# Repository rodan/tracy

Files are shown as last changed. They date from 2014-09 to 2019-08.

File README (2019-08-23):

 gps tracker based on a MSP430F5510 uC with a gprs connection for reporting and command input.

 source:       https://github.com/rodan/tracy 
 author:       Petre Rodan <2b4eda@subdimension.ro>
 license:      GNU GPLv3

Features:
 - both hardware and software are opensource
 - an f-ram chip for input data buffering
 - resilient software architecture
 - all gps/gsm operations controlled by timer interrupts which allows control of both sub-systems in the same time
 - great flexibility given by configuration variables

 prototype pictures available here:  https://photos.app.goo.gl/5ZgdGM5Km6QHHfX5A
 documentation available here:       https://github.com/rodan/tracy/blob/master/doc/tracy_manual.pdf

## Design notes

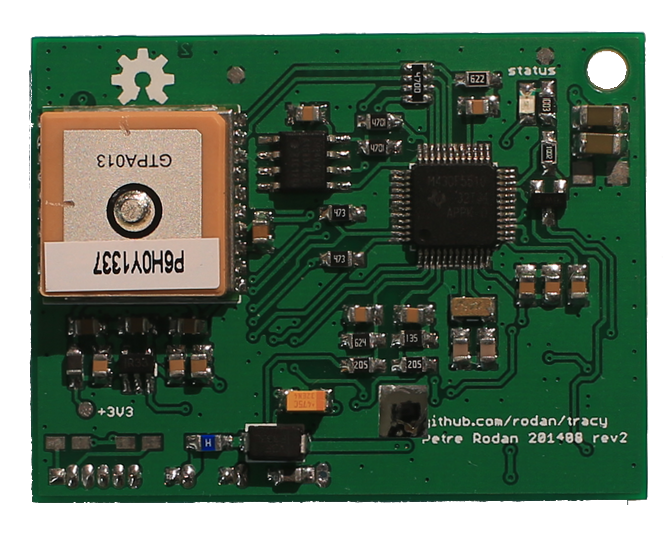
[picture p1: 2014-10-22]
doc/img/front.png

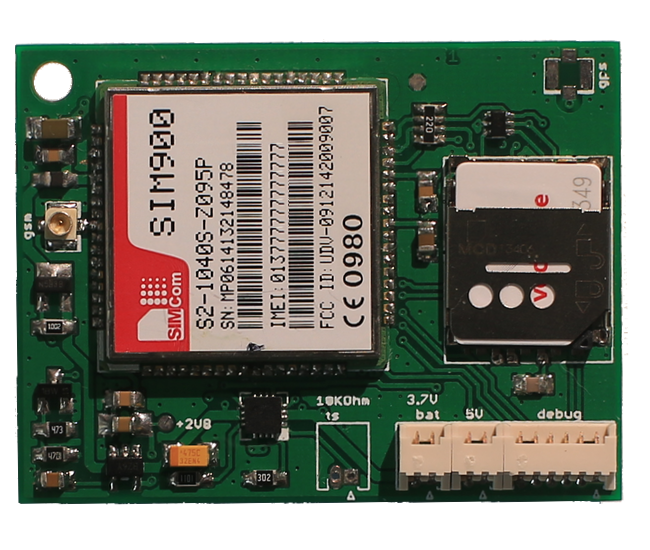
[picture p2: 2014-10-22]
doc/img/back.png

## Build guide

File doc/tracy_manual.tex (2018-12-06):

\documentclass[a4paper,twoside]{refart}

\hfuzz=10pt

\usepackage{etex}
\usepackage{longtable}
\usepackage{graphicx} 
\usepackage[bitheight=6ex]{bytefield}
\usepackage{gensymb}
\usepackage[stable]{footmisc}
\usepackage{multirow}
\usepackage[toc]{glossaries}

\makeglossaries

\usepackage{hyperref}
\hypersetup{
    colorlinks,
    citecolor=black,
    filecolor=black,
    linkcolor=black,
    urlcolor=blue
}

\usepackage{listings} % Required for inserting code snippets
\usepackage[usenames,dvipsnames]{color} % Required for specifying custom colors and referring to colors by name

\usepackage{pgfgantt}
\usepackage{tikz-timing}

\definecolor{highlight}{RGB}{255,251,204} % Code highlight color

\lstdefinelanguage{sms}
{morekeywords={code,gprs?,setup?,fix?,apn,user,pass,srv,port,vref,err.*,spl,spw,spi,spg,sml,smst,smmt,ping,set,default},
sensitive=false,
morestring=[b]",
}

\lstset{
language=sms, % Detects keywords, comments, strings, functions, etc for the language specified
backgroundcolor=\color{highlight}, % Set the background color for the snippet - useful for highlighting
basicstyle=\footnotesize\ttfamily, % The default font size and style of the code
%basicstyle=\ttfamily, % The default font size and style of the code
breakatwhitespace=false, % If true, only allows line breaks at white space
breaklines=true, % Automatic line breaking (prevents code from protruding outside the box)
captionpos=b, % Sets the caption position: b for bottom; t for top
deletekeywords={}, % If you want to delete any keywords from the current language separate them by commas
%escapeinside={\%}, % This allows you to escape to LaTeX using the character in the bracket
firstnumber=1, % Line numbers begin at line 1
frame=single, % Frame around the code box, value can be: none, leftline, topline, bottomline, lines, single, shadowbox
frameround=tttt, % Rounds the corners of the frame for the top left, top right, bottom left and bottom right positions
keywordstyle=\color{Blue}\bf, % Functions are bold and blue
morekeywords={}, % Add any functions no included by default here separated by commas
numbers=left, % Location of line numbers, can take the values of: none, left, right
numbersep=10pt, % Distance of line numbers from the code box
numberstyle=\tiny\color{Gray}, % Style used for line numbers
rulecolor=\color{black}, % Frame border color
showstringspaces=false, % Don't put marks in string spaces
showtabs=false, % Display tabs in the code as lines
stepnumber=5, % The step distance between line numbers, i.e. how often will lines be numbered
stringstyle=\color{Purple}, % Strings are purple
tabsize=2, % Number of spaces per tab in the code
}

\renewcommand*{\familydefault}{\sfdefault}
%\renewcommand*{\familydefault}{\rmdefault}
%\renewcommand*{\familydefault}{\ttdefault}
%\renewcommand*{\familydefault}{\rmdefault{ppl}}

\newglossaryentry{adc}{%
  name={ADC},
  description={analog to digital converter}
}

\newglossaryentry{cell-id}{%
  name={cell ID},
  description={cell identification code - part of the cell tower id broadcast}
}

\newglossaryentry{cell-lac}{%
  name={cell LAC},
  description={location area code - part of the cell tower id broadcast}
}

\newglossaryentry{cell-mcc}{%
  name={cell MCC},
  description={mobile country code - part of the cell tower id broadcast}
}

\newglossaryentry{cell-mnc}{%
  name={cell MNC},
  description={mobile network code - part of the cell tower id broadcast}
}

\newglossaryentry{cell-rxl}{%
  name={cell RXL},
  description={receive signal strength level - part of the cell tower id broadcast}
}

\newglossaryentry{m2m}{%
  name={M2M},
  description={machine to machine data plan - mobile subscription that covers SMS and data but no voice}
}

\newglossaryentry{pdop}{%
  name={PDOP},
  description={(3D) position dilution of precision - a value that describes the measurement's precision based on satellite geometry scattering as viewed from the ground. the lower the number the better. if it's more than 5 the calculated geographical position is not to be taken into account}
}

\newglossaryentry{f-ram}{%
  name={F-RAM},
  description={Ferroelectric RAM, is a type of non-volatile random-access memory that has far greater write-erase cycle performance than eeprom/flash/SD cards and lower power usage than DRAM, but it has storage capacity limitations that makes it more costly}
}

\newenvironment{fulltable}[1][htbp]
 {\begin{table}[#1]%
  \hspace*{-\leftmarginwidth}%
  \begin{minipage}{\fullwidth}}
 {\end{minipage}\end{table}}

\newcommand*\numcircledtikz[1]{\tikz[baseline=(char.base)]{
            \node[shape=circle,draw,fill=orange,inner sep=2pt] (char) {#1};}}

%\newglossaryentry{}{%
%  name={},
%  description={}
%}

\begin{document}
\title{Gps tracking module with gprs connectivity}
\author{Petre Rodan \url{http://www.subdimension.ro}}
\date{created September 2014, revised \today}
\maketitle

\begin{fulltable}
\begin{tabular}{ c p{8cm} }

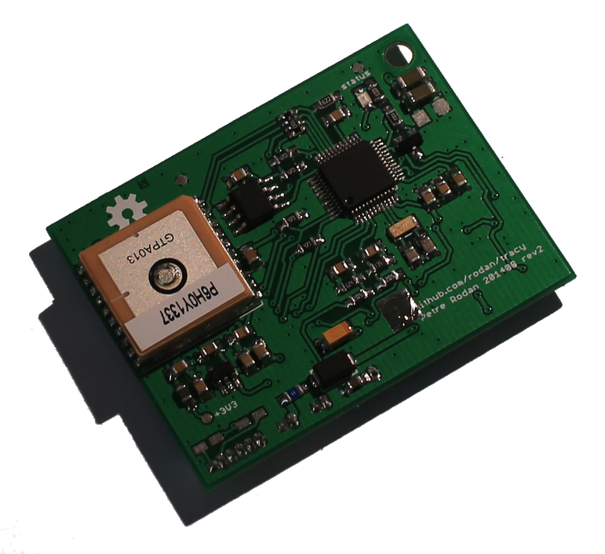
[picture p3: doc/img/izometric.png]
    \raisebox{-\totalheight}{} &
    \textbf{Description:} This module can be used to track goods wherever gsm signal is present. It is optimized for very low power consumption and has configurable timings which would make it fit to any use case scenario.

    \textbf{Main features:} both hardware and software are open-source, an f-ram chip for input data buffering, resilient software architecture, all gps/gsm operations controlled by timer interrupts which allows control of both subsystems in the same time, great flexibility given by configuration variables

    \textbf{Size:} 50mm x 38mm x 9mm
     
    \textbf{Voltage input:} 3.7V battery and optional 5V DC for charging

\end{tabular}
\end{fulltable}

\tableofcontents
\newpage

\section{Principles of operation}
Geographic coordinates are obtained by decoding NMEA sentences received from the GPS chipset and then transmitted via the mobile phone network to a web server. The server stores the received information into a database and provides it on demand to the end-user.

Cell tower identifiers are also transmitted in the same packet and this allows approximate localization when the gps signal is obstructed. When the gsm signal is missing data is being stored on the device and it's transmission will resume once connection is re-established.

\section{What's included}

1 x tracking module \\
1 x GPRS antenna with ufl adapter (manufacturer id: WLS119E1B) \\
2 x 2 pin Molex picoblade connectors and short cable for battery and DC input (manufacturer id: MOLEX 0510210200 and MOLEX 0500798000) \\
1 x 6 pin Molex picoblade connector and crimp terminals for creating a programming cable (manufacturer id: MOLEX 0510210600 and MOLEX 0500798000) \\
1 x shrink tube

Soldering of the wires is needed. Batteries, sim cards and enclosures are not included.

\section{Quick reference guide}

\subsection{Getting started}

\subsubsection{Requirements}

\marginlabel{Warning} Special care must be taken with the gprs antenna. It has to be connected to the connector marked 'gprs' at all times or otherwise the module could be damaged.

This module works best with two power sources. One 3.7V Li-Polymer/Li-Ion cell (at least 2000mAh recommended) and a 5V input DC that is only used for recharging the cell. Only the second one is optional due to the fact that for very short bursts the gprs modem needs more current than the DC input can handle. This circuitry is USB power friendly. If the module gets installed onto a vehicle, a high efficiency DC-DC converter can be provided to lower the voltage from up to 24V to the 5V needed. Double check the polarity on the connectors before attempting to apply any power to the device. Pin 1 is marked on the silkscreen with a small triangle and that represents the ground (negative) terminal for both the battery and the DC inputs.

The user will also need a mobile phone in order to send commands to the module via SMS and a web browser to visualize the generated data.

\subsubsection{SIM cards and initial setup}

Below is a step-by-step guide for installing a local SIM card into the tracking module. The setup of a 'Vodafone prepay card' is shown as an example.

\begin{itemize}
    \item buy a SIM card. any SIM card will do: prepay-ed, subscription (but do keep in mind that no voice transmission will ever be used on this SIM tho), machine to machine (also known as \gls{m2m}). mini SIM form factor cards are needed.
    \item obtain the associated phone number and enter it into your phone's address-book - don't forget to also add the country prefix so you can contact the tracker while abroad.
    \item place the newly purchased SIM card into a mobile phone
    \item if it has no initial credit, fill it with at least 5EUR
    \item make sure no PIN is set on the SIM itself
    \item disable any 'best value plan' the provider might have selected - this SIM will mostly be used to connect to the internet, and it will send a minimal number of SMS messages during the setup process. the only extra options that are needed are the cheapest internet plan available ('100MB internet for 1 Month - 2EUR' for vodafone). also activate data roaming.
    \item disable 'VOX voicemail' by calling \#\#002\#
    \item place the SIMs back into their proper locations: the newly purchased one in the tracker and your old one into the phone.
    \item while inserting the SIM into the tracker write down the 15 IMEI digits that you see written on the SIM900 IC that is adjacent to the SIM holder.
    \item send a SMS from the phone to the tracker that contains:

\begin{lstlisting}
code 5551
\end{lstlisting}

'5551' will need to be replaced by the last 4 digits you wrote down during the previous step

    \item power on the tracker and wait. it only connects to the gsm network every 15 minutes by default and it has a 1 minute interval in which it's actively listening to incoming SMS messages. once the code is received and acknowledged you will get a 'code ok' reply on the phone. from this moment on you can send commands to the tracker.
\end{itemize}

\subsection{gprs setup}

In order for the module to connect to the internet to send out the tracking data it needs a working gprs connection to the mobile service provider. This connection is established only if a set of credentials (\verb"apn", \verb"username" and \verb"password") are used to authenticate the device. You can ask your mobile phone company to provide these. Sometimes one company has customized \verb"apn" and/or \verb"usernmames" for each sim card type, so don't rely on web searches.

Once you get your correct credentials, send them as 3 different SMS commands to the device:

\begin{lstlisting}
apn STRING
\end{lstlisting}
\begin{lstlisting}
user STRING
\end{lstlisting}
\begin{lstlisting}
pass STRING
\end{lstlisting}

\marginlabel{Warning} All strings can be max 20 characters long. If you need more on any of them please contact me.

You can check if all data has been received ok with the following command:

\begin{lstlisting}
gprs?
\end{lstlisting}

\subsection{Web visualization of data}

You can check all the info the tracker sends out by visiting \\ \verb"http://www.subdimension.ro/scripts/l1?i=IMEI_NUMBER" .\\
the \verb"IMEI_NUMBER" is a 15 digit number and it's written on the sim900 module.

This project offers the possibility to advanced users to redirect the tracking data to another web server.
Two commands control the location where HTTP POST packets are sent:

\begin{lstlisting}
srv your.server.com
\end{lstlisting}

\begin{lstlisting}
port port_number
\end{lstlisting}

\marginlabel{Warning} All strings can be max 20 characters long. If you need more on any of them please contact me.

The post request will be sent to \verb"http://your.server.com:port_number/u1". u1 has to be a CGI script (or an alias to one) that decodes the binary packets sent. See Section~\ref{sec:post-packets} for details.

\subsection{SMS commands}

\begin{tabular}{ |l|p{8cm}| }
    \hline
        command & 
\begin{lstlisting}
code STRING
\end{lstlisting} \\
        action & pair a phone to the tracker.
STRING has to be the last 4 digits of the SIM900's IMEI \\ \hline
\end{tabular}

\begin{tabular}{ |l|p{8cm}| }
    \hline
        command & 
\begin{lstlisting}
gprs?
\end{lstlisting} \\
        action & show APN, USER, PASSWORD that are currently used in order to authenticate for a gprs session \\ \hline
\end{tabular}

\begin{tabular}{ |l|p{8cm}| }
    \hline
    \multicolumn{2}{|l|}{} \\
    \hline
        command & 
\begin{lstlisting}
setup?
\end{lstlisting} \\
        action & show a hex value containing current switches \\ \hline
\end{tabular}

\begin{tabular}{ |l|p{8cm}| }
    \hline
        command & 
\begin{lstlisting}
fix?
\end{lstlisting} \\
        action & 
try to send back a GPS fix as a SMS reply \\ \hline
\end{tabular}

\begin{tabular}{ |l|p{8cm}| }
    \hline
        command & 
\begin{lstlisting}
ping
\end{lstlisting} \\
        action & 
a HTTP POST is sent with all available data once this command is received \\ \hline
\end{tabular}

\begin{tabular}{ |l|p{8cm}| }
    \hline
        command & 
\begin{lstlisting}
default
\end{lstlisting} \\
        action & 
restores ALL variables to the factory defaults and reboots the device. the user will have to use the \verb"code" command again to pair it's phone\\ \hline
\end{tabular}

\begin{tabular}{ |l|p{8cm}| }
    \hline
        command & 
\begin{lstlisting}
apn STRING
\end{lstlisting} \\
        default & live.vodafone.com \\
        action & 
set the gprs apn value - max 20 char long

in case STRING is missing, an empty apn is used 

should be set to 'net' for an orange SIM \\ \hline
\end{tabular}

\begin{tabular}{ |l|p{8cm}| }
    \hline
        command & 
\begin{lstlisting}
user STRING
\end{lstlisting} \\
        default & live \\
        action & 
set the gprs user  - max 20 char long

in case STRING is missing, an empty username is used  \\ \hline
\end{tabular}

\begin{tabular}{ |l|p{8cm}| }
    \hline
        command & 
\begin{lstlisting}
pass STRING
\end{lstlisting} \\
        default & vodafone \\
        action & 
set the gprs pass - max 20 char long
in case STRING is missing, an empty password is used  \\ \hline
\end{tabular}

\begin{tabular}{ |l|p{8cm}| }
    \hline
        command & 
\begin{lstlisting}
srv STRING
\end{lstlisting} \\
        default & t.subdimension.ro \\
        action & 
what server to contact in order to send the tracking data \\ \hline
\end{tabular}

\begin{tabular}{ |l|p{8cm}| }
    \hline
        command & 
\begin{lstlisting}
port STRING
\end{lstlisting} \\
        default & 80 \\
        action & 
TCP port used during connection to the server  \\ \hline
\end{tabular}

\begin{tabular}{ |l|p{8cm}| }
    \hline
        command & 
\begin{lstlisting}
vref STRING
\end{lstlisting} \\
        default & 198 \\
        action & 
STRING is a number between 190 and 210 that acts as calibration coefficient to the on board \gls{adc}. only used if the voltage values reported by the module differ from the measured ones \\ \hline
\end{tabular}

\begin{tabular}{ |l|p{8cm}| }
    \hline
        command & 
\begin{lstlisting}
err?
\end{lstlisting} \\
        action & 
shows a hex value in case there were any errors logged in the device. this value gets reset when all power is lost, when an 'err?' command is replied to or after a HTTP POST packet is sent out/stored to \gls{f-ram}. only used for debug  \\ \hline
\end{tabular}

\begin{tabular}{ |l|p{8cm}| }
    \hline
        command & 
\begin{lstlisting}
spt?
\end{lstlisting} \\
        action & 
shows a list of gps related timing values\\ \hline
\end{tabular}

\begin{tabular}{ |l|p{8cm}| }
    \hline
        command & 
\begin{lstlisting}
smt?
\end{lstlisting} \\
        action & 
shows a list of gprs related timing values\\ \hline
\end{tabular}

\begin{tabular}{ |l|p{8cm}| }
    \hline
        commands & 
\begin{lstlisting}
spl STRING
\end{lstlisting}
\begin{lstlisting}
spw STRING
\end{lstlisting}
\begin{lstlisting}
spi STRING
\end{lstlisting}
\begin{lstlisting}
spg STRING
\end{lstlisting}
\begin{lstlisting}
sml STRING
\end{lstlisting}
\begin{lstlisting}
smst STRING
\end{lstlisting}
\begin{lstlisting}
smmt STRING
\end{lstlisting} \\
        action &
timing variables. see section \ref{sub:timing} for details.
\\ \hline
\end{tabular}

\section{Developer guide}
\subsection{Software}

All the documentation, sources and hardware schematics are provided as Open Source in order to encourage further improvements by the community. The TI spy-bi-wire protocol can be used to re-flash the enclosed microcontroller.

Firmware is written in C and it's created to be fully non-blocking and interrupt driven. The server-side scripts are in perl and bash.

Any web server can be used to receive the binary data sent from the tracker. The unpack() function present in perl, python, php will reconstruct the information and make it ready to be inserted into a database. Special care has to be taken so that the web server's reply header is as short as possible. If it's too long the module will not parse it properly and the data flow will be disrupted. In case nginx is used using the following settings are highly recommended:

\begin{lstlisting}
more_clear_headers 'Server';
more_clear_headers 'Date';
more_clear_headers 'Content-Type';
more_clear_headers 'Transfer-Encoding';
more_clear_headers 'Connection';
\end{lstlisting}

Provided scripts have the following run time dependencies (some are optional):

\begin{itemize}
    \item perl at least ver 5.8.2
    \item sqlite at least ver 3.0.0
    \item bash
    \item nginx
    \item fcgi
\end{itemize}

\subsubsection{Tweaking the firmware}

The original source code is kept in a git repository at github.com.
One can grab a copy by running

\begin{lstlisting}
git clone http://github.com/rodan/tracy
\end{lstlisting} 

or by downloading a snapshot archive

\begin{lstlisting}
wget https://github.com/rodan/tracy/archive/master.zip
\end{lstlisting} 

compiling is as easy as
\begin{lstlisting}
cd firmware
make clean
make
\end{lstlisting} 

The following packages are used to compile and manage the firmware:

\begin{itemize}
    \item msp430-gcc (ver 4.6.3\_p20120406 has been used)
    \item msp430-binutils (2.22\_p20120911)
    \item msp430-libc (20120716)
    \item msp430mcu (20120716)
    \item mspdebug (0.22)
\end{itemize}

Burning the firmware can be achieved with any MSP430 programmer that supports SPY-Bi-Wire. 

\marginlabel{Warning} Specialized programmers can detect the 2.8V rail the microcontroller uses and will not send signals with a higher voltage. Anything higher than 3V is just asking for trouble. 

mspdebug can be used to program the firmware:

\begin{lstlisting}
mspdebug rf2500 "prog proj.elf"
\end{lstlisting}

\subsubsection{HTTP POST packets}
\label{sec:post-packets}

Tracking information is sent to the server by TCP packets via the HTTP POST method. A web server is thus needed to receive the data and feed it to the parsing script (see \verb"server/scripts/u1" in the repository).

In order to have a good bandwidth usage the data is sent in a binary format and the \gls{f-ram} chip that is being used allows the data to be buffered and sent out at set intervals. Most scripting languages have an unpack() function that can correctly decode these packets. A sample perl script is provided in the repository (see \verb"server/scripts/l1").

\begin{figure}[htbp]
  \centering
  \begin{bytefield}{32}
    \bitheader{0,0} \\
    \begin{rightwordgroup}{HTTP \\ POST \\ method \\ header}
        \bitbox{32}{POST /u1 HTTP/1.0} \\
        \bitbox{32}{Host: trk.subdimension.ro} \\
        \bitbox{32}{Content-Type: application/binary} \\
        \bitbox{32}{Content-Length: 00000}
    \end{rightwordgroup} \\

    \begin{rightwordgroup}{one\\ segment}
    \wordbox[lrt]{1}{
      \parbox{0.6\width}{\centering at least one subsegment}} \\
    \skippedwords \\
    \wordbox[lrb]{1}{} 
  \end{rightwordgroup}
  \end{bytefield}
  \caption{packet format}
  \label{fig:packetformat}
\end{figure}

Each positional measurement will be placed in a subsegment. At least one of these subsegments will constitute one segment that is sent out together with a HTTP header to create an HTTP POST request (see Figure~\ref{fig:packetformat}).

\begin{figure}[htbp]
  \centering
  \begin{bytefield}{32}
    \bitheader{0,7-8,15-16,23-24,31} \\
    \begin{rightwordgroup}{subsegment \\ header}
        \bitbox{16}{version} &&
        \bitbox[tlr]{16}{} \\
        \wordbox[lr]{1}{\parbox{0.6\width}{\centering 15 byte IMEI}} \\
        \skippedwords \\
        \wordbox[lrb]{1}{} \\ 
        \bitbox{16}{settings} &&
        \bitbox{16}{$V_{BAT}$} \\
        \bitbox{16}{$V_{RAW}$} &&
        \bitbox{16}{errors} \\
        \bitbox{16}{message id} &&
        \bitbox{8}{payload descriptor} &&
        \bitbox[tlr]{8}{} \\
        \bitbox[rl]{32}{timestamp} \\
        \bitbox[rlb]{8}{} &&
        \bitbox[tl]{24}{}
    \end{rightwordgroup} \\
    \begin{rightwordgroup}{payload}
    \\
    \bitbox[lrb]{32}{\dots gps and/or gprs payload}
    \end{rightwordgroup}
  \end{bytefield}
  \caption{subsegment format}
  \label{fig:subsegment-format}
\end{figure}

\begin{figure}[htbp]
  \centering
  \begin{bytefield}{32}
    \bitheader{0,7-8,15-16,23-24,31} \\
    \begin{rightwordgroup}{gps \\ data}
        \bitbox{32}{latitude (float)} \\
        \bitbox{32}{longitude (float)} \\
        \bitbox{16}{\gls{pdop}} &&
        \bitbox{16}{speed} \\
        \bitbox{16}{heading} &&
        \bitbox{16}{system time} \\
        \bitbox{16}{system time} &&
        \bitbox[btl]{16}{geofence distance} \\
        \bitbox[btr]{16}{geofence distance} &&
        \bitbox{16}{geofence bearing}
    \end{rightwordgroup}
  \end{bytefield}
  \caption{gps payload}
  \label{fig:gps_payload}
\end{figure}

\begin{figure}[htbp]
  \centering
  \begin{bytefield}{32}
    \bitheader{0,7-8,15-16,23-24,31} \\
    \begin{rightwordgroup}{gprs \\ data}
        \bitbox{16}{\gls{cell-rxl}} &&
        \bitbox{16}{\gls{cell-mcc}} \\
        \bitbox{16}{\gls{cell-mnc}} &&
        \bitbox{16}{\gls{cell-id}} \\
        \bitbox{16}{\gls{cell-lac}}
    \end{rightwordgroup}
  \end{bytefield}
  \caption{gprs payload}
  \label{fig:gprs_payload}
\end{figure}

Each subsegment (shown in Figure~\ref{fig:subsegment-format}) has a header containing the timestamp at the time of the fix, modem IMEI, system voltages, previous errors detected, basic device configuration, an auto increment id and a byte that describes the type of the positional data. This can either be a GPS fix (Figure~\ref{fig:gps_payload}) and/or one up to four tower identification strings (Figure~\ref{fig:gprs_payload}).

The tower identification strings are post-processed on the web server and a \emph{very} approximate geographic position is obtained.

These subsegments are simply concatenated together to constitute the final segment being sent. The size of one such segment varies but SIM900's internal buffering limits it up to 1000bytes. During one GPRS session one up to \verb"MAX_SEG" are sent out at a time. If GPRS connections cannot be established for a long interval and \verb"MAX_SEG" is reached then the oldest segment is freed in order to make place for new data.

\newpage
\subsubsection{Timings and intervals}
\label{sub:timing}

This tracking module allows fine-grained timing customization. It can either preserve battery life for more than a month when sparse measurements are being made or it can record positional data every 10 seconds if needed. Either behavior can be set by the user via SMS commands, without the need to change the firmware.

A 'reset to factory settings' function is also provided in case the user needs to return to known-good timing values.

Default values for the gps intervals are depicted in Table~\ref{gps_diag}. The yellow time intervals are configurable: the entire loop takes 180 seconds - from which in the first 135 the gps module is powered off, a 45 sec warmup brings the device to life and it should be enough to ensure a good fix at the end of that interval. During the invalidation period the module will choose the fix with the best \gls{pdop} value and that will get stored into \gls{f-ram}.

\begin{table}[ht]
\begin{ganttchart}[
vgrid,
bar/.append style={fill=yellow, rounded corners=3pt},
bar left shift=.15,
bar right shift=-.15,
bar top shift=.4,
bar height=.2,
group left shift=0,
group right shift=0,
group peaks tip position=0,
group peaks height=.4,
milestone/.append style={fill=orange, rounded corners=3pt}
]{0}{18}
\ganttbar{loop}{0}{18} \\
\ganttbar{warmup}{13}{18} \\
\ganttbar{invalidate}{16}{18} \\
\ganttmilestone{store fix}{18} \\
\ganttbar[bar/.append style={fill=gray}]{gps off/on}{0}{12}
\ganttbar[bar/.append style={fill=red}]{}{13}{18}
\end{ganttchart}
\caption{\em default time intervals for the gps subsystem}
\label{gps_diag}
\end{table}

If much more frequent gps data needs to be acquired, ie\\
\verb"loop interval" $\leq$ \verb"warmup interval" + \verb"30s" \\
then the gps will never be powered off. See Table~\ref{gps_diag_10s} for an example where all gps intervals are set to 10 seconds.

\begin{table}[ht]
\begin{ganttchart}[
vgrid,
bar/.append style={fill=yellow, rounded corners=3pt},
bar left shift=.15,
bar right shift=-.15,
bar top shift=.4,
bar height=.2,
group left shift=0,
group right shift=0,
group peaks tip position=0,
group peaks height=.4,
milestone/.append style={fill=orange, rounded corners=3pt}
]{0}{18}
\ganttbar{loop}{0}{18} \\
\ganttbar{warmup}{0}{18} \\
\ganttbar{invalidate}{0}{18} \\
\ganttmilestone{store fix}{18} \\
\ganttbar[bar/.append style={fill=gray}]{gps off/on}{0}{0}
\ganttbar[bar/.append style={fill=red}]{}{0}{18}
\end{ganttchart}
\caption{\em 10s loop for the gps subsystem}
\label{gps_diag_10s}
\end{table}

As a rule of thumb try to have at least 45 seconds as the warmup interval in case the gps gets powered off.
And given the fact that the gps is set to send data every two seconds to the microcontroller make sure the invalidation interval is at least 6-8 seconds.

Unlike the gps, the gsm modem needs to be kept off most of the time since it is by far the most power hungry subsystem on this module.
Also a little known fact is that internet data plans have small hidden costs that can add up in time. Sometimes there is a minimum data unit (between 1-10kbytes) that gets counted for every established gprs connection, also while in roaming each gprs initialization has a cost associated with it.
So depending on your gsm provider and use case, you want to get the best trade-off using the configurable variables described in this section.

The modem gets woken up by one of these two triggers:

\begin{itemize}
    \item a periodic check for any new SMS command to be acted upon. this wake-up has no costs associated with it if no SMS reply is to be sent back to the user \\ trigger controlled by \verb"gprs loop interval"
    \item upload of data stored in \gls{f-ram} via gprs. SMS commands are also accepted at this point. this trigger can happen either because enough data has piled up in the memory, one of the \verb"gprs tx interval"s has been reached, the \verb"ping" command was received or the module just started to move after being stationary. \\ trigger controlled by \verb"gprs static tx interval" when the module is not moving or \verb"gprs moving tx interval" otherwise.
\end{itemize}

Whatever is the reason for the modem startup, the neighboring tower cell IDs are stored as a secondary (but less precise) positioning method. 

The module behavior when using the default gprs interval settings is shown in a simplified form in Table~\ref{gsm_diag}. Every 900 seconds the \verb"gprs loop interval" wakes up the modem for a 2 minute period in which possible SMSs are parsed and tower cell IDs are captured.

A movement that was detected triggers an upload of data and makes the next upload happen after 600sec (\verb"gprs moving tx interval"). The next transfer will happen after 3600sec (\verb"gprs static tx interval") since the module is not moving.

\begin{table}[ht]
\scalebox{0.48}{
\begin{tikztimingtable}
 loop trigger & 1H 9L 1H 9L 1H 9L 1H 9L 1H 9L 1H 9L 1H 9L 1H 9L 1H 4L\\
 movement & 2L 3H 80L \\
 tx trigger & 2L 1H 6L 1H 36L 1H 36L 1H 1L \\
\extracode
    \tablerules
\end{tikztimingtable}
}
\caption{\em default module behavior}
\label{gsm_diag}
\end{table}

\subsubsection{List of timing variables}

\label{sms:spl}
\begin{tabular}{ |l|c|c|c|c| }
    \hline
    \multicolumn{1}{|c|}{\multirow{2}{*}{\textbf{gps loop interval}}} & \multicolumn{3}{|c|}{value} & \multicolumn{1}{|c|}{\multirow{2}{*}{unit}} \\ \cline{2-4}
    \multicolumn{1}{|c|}{} & min & default & max & \\ \hline
    value & 10 & 180 & 65535 & seconds \\ \hline
    sms command to set & \multicolumn{4}{|l|}{\textbf{spl} $value$} \\ \hline
    sms command to view & \multicolumn{4}{|l|}{\textbf{spt?}} \\ \hline
    description & \multicolumn{4}{|p{7cm}|}{sets the interval between two gps measurement sessions} \\ \hline
\end{tabular}

\label{sms:spw}
\begin{tabular}{ |l|c|c|c|c| }
    \hline
    \multicolumn{1}{|c|}{\multirow{2}{*}{\textbf{gps warmup interval}}} & \multicolumn{3}{|c|}{value} & \multicolumn{1}{|c|}{\multirow{2}{*}{unit}} \\ \cline{2-4}
    \multicolumn{1}{|c|}{} & min & default & max & \\ \hline
    value & 0 & 45 & 65535 & seconds \\ \hline
    sms command to set & \multicolumn{4}{|l|}{\textbf{spw} $value$} \\ \hline
    sms command to view & \multicolumn{4}{|l|}{\textbf{spt?}} \\ \hline
    description & \multicolumn{4}{|p{7cm}|}{time interval between gps powerup and the actual measurement} \\ \hline
\end{tabular}

\label{sms:spi}
\begin{tabular}{ |l|c|c|c|c| }
    \hline
    \multicolumn{1}{|c|}{\multirow{2}{*}{\textbf{gps invalidate interval}}} & \multicolumn{3}{|c|}{value} & \multicolumn{1}{|c|}{\multirow{2}{*}{unit}} \\ \cline{2-4}
    \multicolumn{1}{|c|}{} & min & default & max & \\ \hline
    value & 0 & 20 & 65535 & seconds \\ \hline
    sms command to set & \multicolumn{4}{|l|}{\textbf{spi} $value$} \\ \hline
    sms command to view & \multicolumn{4}{|l|}{\textbf{spt?}} \\ \hline
    description & \multicolumn{4}{|p{6.8cm}|}{time interval at the end of the measurement session during which the gps fix with the best \gls{pdop} is searched for} \\ \hline
\end{tabular}

\verb"spi" must be a smaller value then \verb"spl".

\label{sms:spg}
\begin{tabular}{ |l|c|c|c|c| }
    \hline
    \multicolumn{1}{|c|}{\multirow{2}{*}{\textbf{gps geofence trigger}}} & \multicolumn{3}{|c|}{value} & \multicolumn{1}{|c|}{\multirow{2}{*}{unit}} \\ \cline{2-4}
    \multicolumn{1}{|c|}{} & min & default & max & \\ \hline
    value & 0 & 300 & 65535 & meters \\ \hline
    sms command to set & \multicolumn{4}{|l|}{\textbf{spg} $value$} \\ \hline
    sms command to view & \multicolumn{4}{|l|}{\textbf{spt?}} \\ \hline
    description & \multicolumn{4}{|p{7cm}|}{minimal distance between two consecutive fixes at which the device is considered non-stationary} \\ \hline
\end{tabular}

Heavy cloud coverage or large adjacent buildings can obscure or create multipath errors in the gps signal detection. It is thus advisable to not set the \textbf{spg} variable too low in order to minimize false-positives.

\label{sms:sml}
\begin{tabular}{ |l|c|c|c|c| }
    \hline
    \multicolumn{1}{|c|}{\multirow{2}{*}{\textbf{gprs loop interval}}} & \multicolumn{3}{|c|}{value} & \multicolumn{1}{|c|}{\multirow{2}{*}{unit}} \\ \cline{2-4}
    \multicolumn{1}{|c|}{} & min & default & max & \\ \hline
    value & 180 & 900 & 65535 & seconds \\ \hline
    sms command to set & \multicolumn{4}{|l|}{\textbf{sml} $value$} \\ \hline
    sms command to view & \multicolumn{4}{|l|}{\textbf{smt?}} \\ \hline
    description & \multicolumn{4}{|p{7cm}|}{time interval between two gsm connection attempts (these are used to get tower id data and to receive and parse sms commands)} \\ \hline
\end{tabular}

each application needs a different trade-off between sms responsiveness and low power consumption.

\label{sms:smst}
\begin{tabular}{ |l|c|c|c|c| }
    \hline
    \multicolumn{1}{|c|}{\multirow{2}{*}{\textbf{gprs static tx interval}}} & \multicolumn{3}{|c|}{value} & \multicolumn{1}{|c|}{\multirow{2}{*}{unit}} \\ \cline{2-4}
    \multicolumn{1}{|c|}{} & min & default & max & \\ \hline
    value & 180 & 3600 & 65535 & seconds \\ \hline
    sms command to set & \multicolumn{4}{|l|}{\textbf{smst} $value$} \\ \hline
    sms command to view & \multicolumn{4}{|l|}{\textbf{smt?}} \\ \hline
    description & \multicolumn{4}{|p{7cm}|}{time interval between two HTTP POSTs when the device is stationary (see \textbf{spg} \ref{sms:spg})} \\ \hline
\end{tabular}

\label{sms:smmt}
\begin{tabular}{ |l|c|c|c|c| }
    \hline
    \multicolumn{1}{|c|}{\multirow{2}{*}{\textbf{gprs moving tx interval}}} & \multicolumn{3}{|c|}{value} & \multicolumn{1}{|c|}{\multirow{2}{*}{unit}} \\ \cline{2-4}
    \multicolumn{1}{|c|}{} & min & default & max & \\ \hline
    value & 180 & 600 & 65535 & seconds \\ \hline
    sms command to set & \multicolumn{4}{|l|}{\textbf{smmt} $value$} \\ \hline
    sms command to view & \multicolumn{4}{|l|}{\textbf{smt?}} \\ \hline
    description & \multicolumn{4}{|p{7cm}|}{time interval between two HTTP POSTs when the device is moving (see \textbf{spg} \ref{sms:spg})} \\ \hline
\end{tabular}

all the timings in this section are used for scheduling the respective actions. the final timestamps received in the web reports will not follow exactly the values entered. this happens because the device tries to get the best fix possible in the \textbf{spi} interval based on \gls{pdop} measurements and also because most actions performed are dependent on both outside factors (how quickly a good fix is received from the gps, mobile service availability, how many sms actions need to be executed) as well as local interactions (the gprs modem can only perform one task at any given time).

\newpage
\subsection{Hardware}

\subsubsection{Absolute maximum ratings}

\begin{tabular}{ |c|c|l|c|c|c| }
    \hline
    \multicolumn{3}{|c|}{} & \multicolumn{2}{|c|}{value} & unit \\ \cline{4-6}
    \multicolumn{3}{|c|}{} & min & max & \\ \hline
    \multicolumn{1}{|c|}{\multirow{2}{*}{$V_{I}$}} & \multicolumn{1}{|c|}{\multirow{2}{*}{input voltage}} &    IN (with respect to VSS) & -0.3    & 28  & V \\ \cline{3-6}
                &                       &  VBAT (with respect to VSS)   & -0.3  & 5   & V \\ \hline
    $V_{IO}$ & \multicolumn{2}{|l|}{IO voltage thru the debug connector}                      & -0.3  & 3.1 & V \\ \hline
    $T_{stg}$   & \multicolumn{2}{|l|}{storage temperature}             & -65   & 150 & \degree C \\  \hline
    $T_{op}$   & \multicolumn{2}{|l|}{operating temperature}          & 0     & 125 & \degree C \\  \hline
\end{tabular}

Stresses above those listed in absolute maximum ratings may cause permanent damage to the device. This is a stress rating only, functional operation of the device at these or any other conditions above those indicated in the operational section of this specification is not implied. Exposure to absolute maximum rating conditions for extended periods may affect device reliability.

\subsubsection{Electrical characteristics}

\begin{tabular}{ |c|l|c|c|c|c| }
    \hline
    \multicolumn{2}{|c|}{} & \multicolumn{3}{|c|}{value} & unit \\ \cline{3-6}
    \multicolumn{2}{|c|}{} & min & typ & max & \\ \hline
    $V_{I}$ & input voltage range                      & 4.35  & 5     & 6.4  & V \\ \hline
    $I_{I}$ & input current                            & X     & X     & 1.5  & A \\ \hline
    $V_{BAT}$ & battery voltage range                  & 3.5   &       & 4.1  & V \\ \hline
    $I_{BAT}$ & battery current on sim900 poweron      &       &       & 3200 & mA \\ \hline
    $I_{BAT}$ & battery current while sim900 tx        &       &       & 1600 & mA \\ \hline
    $I_{BAT}$ & battery current while gps on           &       & 25    & 45   & mA \\ \hline
    $I_{BAT}$ & battery current while sleeping         & 70    &       & 75   & $\mu$A \\ \hline
    $I_{CHG}$ & battery charging current \footnotemark &       & 0.3   &   & A \\ \hline
    $V_{IO}$ & IO voltage thru the debug connector     & 0     &       & 2.8  & V \\ \hline
\end{tabular}

\footnotetext{The charging current is configurable by changing the value of R11. See the module schematic and the bq24072 datasheet for details}

\subsubsection{Components}

\begin{fulltable}
\begin{tabular}{ c c }
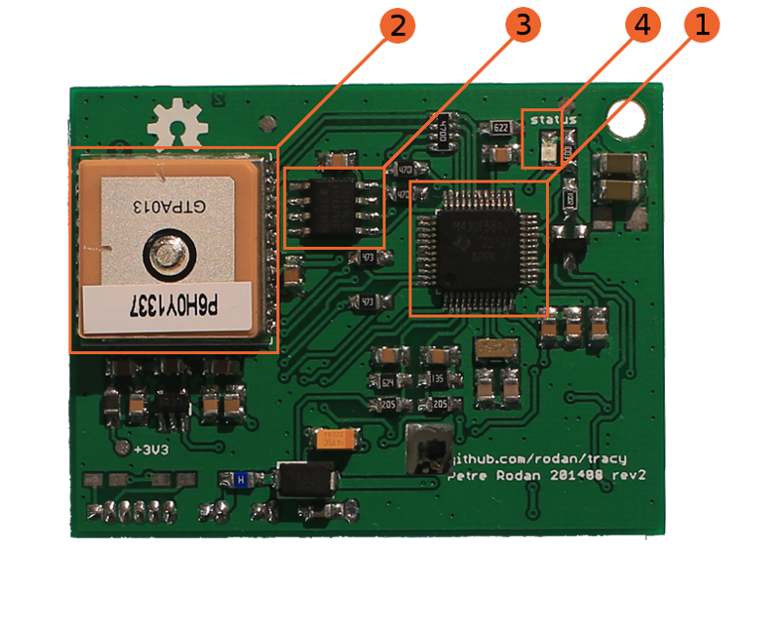
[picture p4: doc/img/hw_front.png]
    \raisebox{-\totalheight}{} &
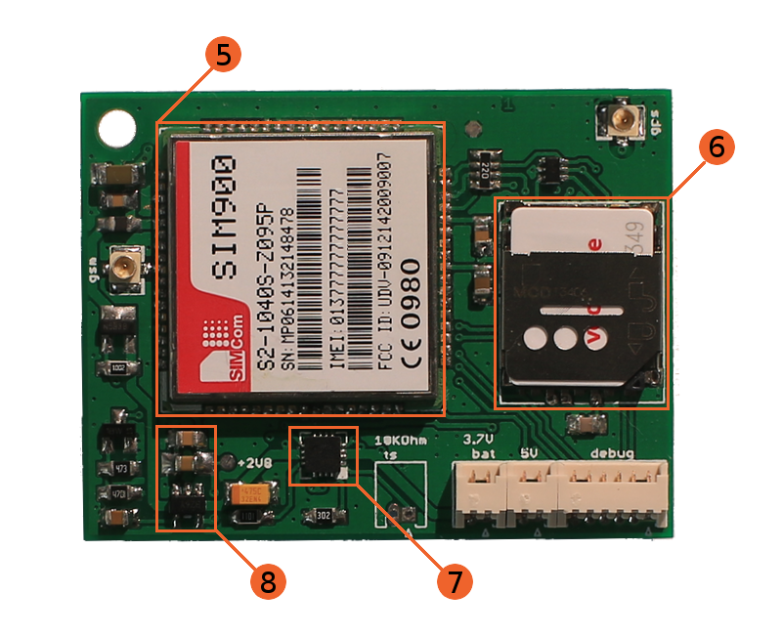
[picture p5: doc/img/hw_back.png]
    \raisebox{-\totalheight}{}
\end{tabular}
\end{fulltable}

\marginlabel{\numcircledtikz{1} MSP430F5510 mixed signal microcontroller}
    \begin{itemize}
        \item 16bit RISC architecture with 32KB flash and 4KB of SRAM
        \item low supply voltage - 2.8V used in this implementation
        \item ultra-low power consumption
        \item 10bit \gls{adc} - both the battery voltage and input voltage levels are kept in check
        \item 4 16bit timers with interrupt generation - used to synchronize all processes
        \item real-time clock - keeps calendar data and the clock when gps signal is missing
        \item port mapping controller - allows digital functions to be switched between different ports
        \item watchdog, brown out reset - ensures the system runs in stable parameters
    \end{itemize}

\marginlabel{\numcircledtikz{2} MT3339 MediaTek GPS chipset}
    \begin{itemize}
        \item tiny gps module that can track 22 satellites at any given moment
        \item even if the module is mostly shut down to conserve power, the backup voltage is always provided thus ensuring a fast time-to-fix when started up
        \item automatic antenna switching detects external antennas
    \end{itemize}

\marginlabel{\numcircledtikz{3} FM24CL64B-G F-RAM IC}
    \begin{itemize}
        \item additional 8kbytes of \gls{f-ram} for data buffering and storage
    \end{itemize}

\marginlabel{\numcircledtikz{4} status LED}
    \begin{itemize}
        \item very high efficiency LED that uses 28 $\mu A$ while lit
        \item very faint blips every two seconds while gps is on and there is no usable gps signal
        \item less faint blips every two seconds while gps is on and gps signal is fine
        \item full brightness for 2 seconds while modem powers up
    \end{itemize}

\marginlabel{\numcircledtikz{5} SIM900 quad-band GSM/GPRS engine}
    \begin{itemize}
        \item GSM 850MHz, EGSM 900MHz, DCS 1800MHz, PCS 1900MHz frequencies are supported
        \item a dedicated user-provided micro SIM is needed to connect to the mobile phone network of choice. \gls{m2m} SIMs also work since voice is never used in this application.
    \end{itemize}

\marginlabel{\numcircledtikz{6} SIM card}
    MICRO form factor SIM card holder

\marginlabel{\numcircledtikz{7} BQ24072 power path management IC}
    \begin{itemize}
        \item allows charging of the Li-Ion/LiPo cell from a USB friendly 5V source
        \item maximum charging current is limited to 300mA
    \end{itemize}

\marginlabel{\numcircledtikz{8} 2.8V rail}
    the only power rail that remains on during microcontroller standby intervals. it can be used to power low voltage sensors/accelerometers/etc via the programming connector.

\newpage
\subsubsection{Connectors}

\begin{fulltable}
    \centering
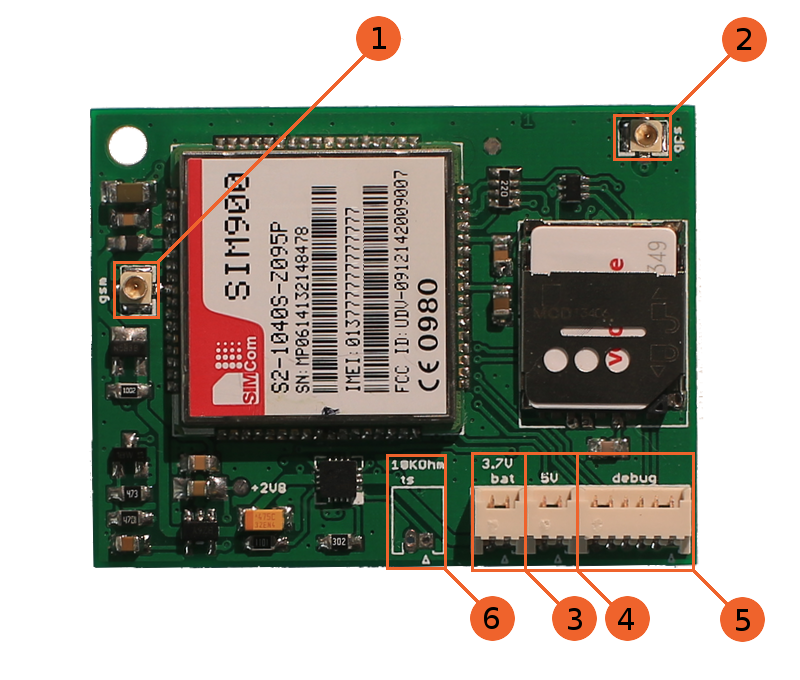
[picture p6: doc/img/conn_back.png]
    {} 
\end{fulltable}

for all pin connectors, pin 1 is marked by a small triangle in the silkscreen

\begin{tabular}{ |l|p{8cm}| }
    \hline
    \multicolumn{2}{|l|}{\numcircledtikz{1} gsm antenna} \\
    \hline
        connector & UFL \\
         & \begin{center}  \end{center} \\ \hline
        silkscreen & \verb"gsm" \\ \hline
        use & it is mandatory to connect the enclosed antenna via this connector \\
    \hline
    \multicolumn{2}{|l|}{pin assignments} \\
    \hline
        shroud   &   GND \\
        center   &   signal \\
    \hline
\end{tabular}

\begin{tabular}{ |l|p{8cm}| }
    \hline
    \multicolumn{2}{|l|}{\numcircledtikz{2} gps antenna} \\
    \hline
        connector & UFL \\
         & \begin{center}  \end{center} \\ \hline
        silkscreen & \verb"gps" \\ \hline
        use & the gps module provides a small patch antenna but one could improve signal reception by using an external one connected here\\
    \hline
    \multicolumn{2}{|l|}{pin assignments} \\
    \hline
        shroud   &   GND \\
        center   &   signal \\
    \hline
\end{tabular}

\begin{tabular}{ |l|p{8cm}| }
    \hline
    \multicolumn{2}{|l|}{\numcircledtikz{3} LiPo/Li-Ion 1 cell battery} \\
    \hline
        connector & Molex 053048-0210 \\
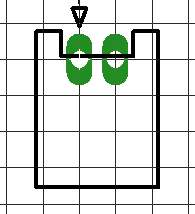
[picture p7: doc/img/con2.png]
        footprint & \begin{center}  \end{center} \\ \hline
        silkscreen & \verb"3.7V bat"  \\ \hline
        use & 1 cell (3.7V) rechargeable Li-Ion or Li polymer battery \\
    \hline
    \multicolumn{2}{|l|}{pin assignments} \\
    \hline
        1   &   GND \\
        2   &   +3.7V \\
    \hline
\end{tabular}

\begin{tabular}{ |l|p{8cm}| }
    \hline
    \multicolumn{2}{|l|}{\numcircledtikz{4} 5V DC input} \\
    \hline
        connector & Molex 053048-0210 \\
        footprint & \begin{center}  \end{center} \\ \hline
        silkscreen & \verb"5V" \\ \hline
        use & 5V DC either from a USB connection or a DCDC converter. used only to charge the included battery with a current up to 300mA \\
    \hline
    \multicolumn{2}{|l|}{pin assignments} \\
    \hline
        1   &   GND \\
        2   &   +5V \\
    \hline
\end{tabular}

\begin{tabular}{ |l|p{8cm}| }
    \hline
    \multicolumn{2}{|l|}{\numcircledtikz{5} programming/debug connector} \\
    \hline
        connector & Molex 053048-0610 \\
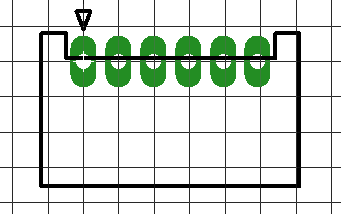
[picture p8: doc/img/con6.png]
        footprint & \begin{center}  \end{center} \\ \hline
        silkscreen & \verb"debug" \\ \hline
        use & pins 3-6 are used for TI's spy-bi-wire protocol in order to program or to debug the microcontroller. pins 1 and 2 can have a custom assignation \\
    \hline
    \multicolumn{2}{|l|}{pin assignments} \\
    \hline
        1   &   P4.1 - context dependent microcontroller port \\
        2   &   P4.0 - context dependent microcontroller port \\
        3   &   2.8V - VCC OUT \\
        4   &   TEST \\
        5   &   RST \\
        6   &   GND \\
    \hline
\end{tabular}

\begin{tabular}{ |l|p{8cm}| }
    \hline
    \multicolumn{2}{|l|}{\numcircledtikz{6} battery thermistor} \\
    \hline
        connector & Molex 053048-0210 \\
        footprint & \begin{center}  \end{center} \\ \hline
        silkscreen & \verb"10KOhm ts" \\ \hline
        use & some battery packs provide this component as a charge ending protection. by default this connector is unpopulated and if it's use is required the 10K resistor located on the other side of the PCB needs to be removed \\
    \hline
    \multicolumn{2}{|l|}{pin assignments} \\
    \hline
        1   &   10K NTC thermistor \\
        2   &   10K NTC thermistor (also GND)\\
    \hline
\end{tabular}

\newpage

%\glsaddall
\printglossaries
%\printglossary[type=acronymdesc,style=altlist]

%\printnoidxglossary[type=main,sort=word]
%\printnoidxglossary[type=symbols,sort=use]

%\renewcommand*{\glsnamefont}[1]{\textmd{#1}}

%\printnoidxglossary[type=index,style=mcolindexgroup,sort=word]

\end{document}

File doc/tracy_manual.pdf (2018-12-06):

## Gps tracking module with gprs connectivity

Petre Rodan http: // www. subdimension. ro (http://www.subdimension.ro)

created September 2014, revised December 6, 2018

Description: This module can be used to track goods wherever gsm signal is present. It is optimized for very low power consumption and has configurable timings which would make it fit to any use case scenario. Main features: both hardware and software are opensource, an f-ram chip for input data buffering, resilient software architecture, all gps/gsm operations controlled by timer interrupts which allows control of both subsystems in the same time, great flexibility given by configuration variables
Size: 50mm x 38mm x 9mm
Voltage input: 3.7V battery and optional 5V DC for charging

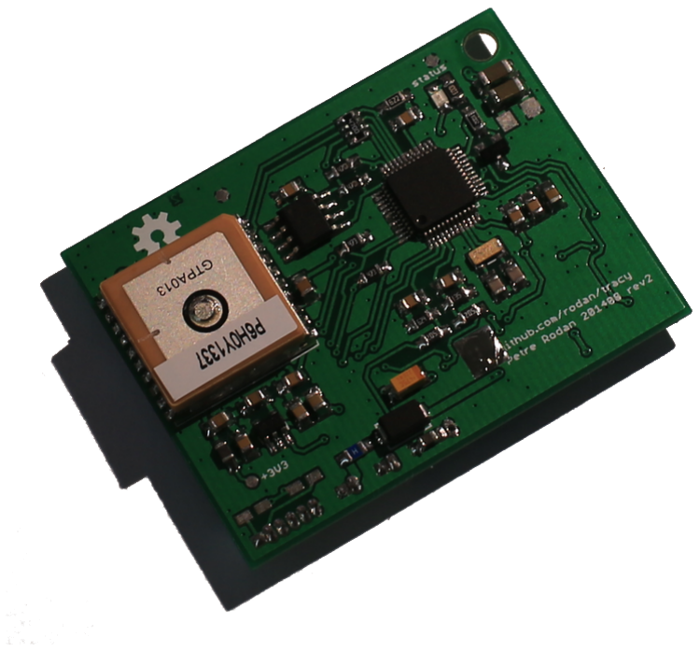
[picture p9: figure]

Contents

1 Principles of operation | 3
2 What’s included | 3
3 Quick reference guide | 3
4 Developer guide | 7

### 1 Principles of operation

Geographic coordinates are obtained by decoding NMEA sentences received from the GPS chipset and then transmitted via the mobile phone network to a web server. The server stores the received information into a database and provides it on demand to the end-user.

Cell tower identifiers are also transmitted in the same packet and this allows approximate localization when the gps signal is obstructed. When the gsm signal is missing data is being stored on the device and it’s transmission will resume once connection is re-established.

### 2 What’s included

1 x tracking module
1 x GPRS antenna with ufl adapter (manufacturer id: WLS119E1B)
2 x 2 pin Molex picoblade connectors and short cable for battery and DC input (manufacturer id: MOLEX 0510210200 and MOLEX 0500798000) 1 x 6 pin Molex picoblade connector and crimp terminals for creating a programming cable (manufacturer id: MOLEX 0510210600 and MOLEX 0500798000)
1 x shrink tube

Soldering of the wires is needed. Batteries, sim cards and enclosures are not included.

### 3 Quick reference guide

### 3.1 Getting started

3.1.1 Requirements

Warning | Special care must be taken with the gprs antenna. It has to be connected to the connector marked ’gprs’ at all times or otherwise the module could be damaged.
| This module works best with two power sources. One 3.7V Li-Polymer/Li-Ion cell (at least 2000mAh recommended) and a 5V input DC that is only used for recharging the cell. Only the second one is optional due to the fact that for very short bursts the gprs modem needs more current than the DC input can handle. This circuitry is USB power friendly. If the module gets installed onto a vehicle, a high efficiency DC-DC converter can be provided to lower the voltage from up to 24V to the 5V needed. Double check the polarity on the connectors before attempting to apply any power to the device. Pin 1 is marked on the silkscreen with a small triangle and that represents the ground (negative) terminal for both the battery and the DC inputs.
| The user will also need a mobile phone in order to send commands to the module via SMS and a web browser to visualize the generated data.

3.1.2 SIM cards and initial setup

| Below is a step-by-step guide for installing a local SIM card into the tracking module. The setup of a ’Vodafone prepay card’ is shown as an example.
| • buy a SIM card. any SIM card will do: prepay-ed, subscription (but do keep in mind that no voice transmission will ever be used on this SIM tho), machine to machine (also known as M2M). mini SIM form factor cards are needed.

- obtain the associated phone number and enter it into your phone’s address-book - don’t forget to also add the country prefix so you can contact the tracker while abroad.
- place the newly purchased SIM card into a mobile phone
- if it has no initial credit, fill it with at least 5EUR
- make sure no PIN is set on the SIM itself
- disable any ’best value plan’ the provider might have selected - this SIM will mostly be used to connect to the internet, and it will send a minimal number of SMS messages during the setup process. the only extra options that are needed are the cheapest internet plan available (’100MB internet for 1 Month - 2EUR’ for vodafone). also activate data roaming.
- disable ’VOX voicemail’ by calling ##002#
- place the SIMs back into their proper locations: the newly purchased one in the tracker and your old one into the phone.
- while inserting the SIM into the tracker write down the 15 IMEI digits that you see written on the SIM900 IC that is adjacent to the SIM holder.
- send a SMS from the phone to the tracker that contains:
✞ | ☎

code 5551

✝ | ✆

’5551’ will need to be replaced by the last 4 digits you wrote down during the previous step

- power on the tracker and wait. it only connects to the gsm network every 15 minutes by default and it has a 1 minute interval in which it’s actively listening to incoming SMS messages. once the code is received and acknowledged you will get a ’code ok’ reply on the phone. from this moment on you can send commands to the tracker.

### 3.2 gprs setup

In order for the module to connect to the internet to send out the tracking data it needs a working gprs connection to the mobile service provider. This connection is established only if a set of credentials (apn, username and password) are used to authenticate the device. You can ask your mobile phone company to provide these. Sometimes one company has customized apn and/or usernmames for each sim card type, so don’t rely on web searches.

Once you get your correct credentials, send them as 3 different SMS commands to the device:

✞ | ☎

apn STRING

✝ | ✆
✞ | ☎

u s e r STRING

✝ | ✆
✞ | ☎

p a s s STRING

✝ | ✆
Warning | All strings can be max 20 characters long. If you need more on any of them please contact me.
| You can check if all data has been received ok with the following command:

✞ | ☎

gprs ?

✝ | ✆

### 3.3 Web visualization of data

You can check all the info the tracker sends out by visiting http://www.subdimension.ro/scripts/l1?i=IMEI_NUMBER .
the IMEI_NUMBER is a 15 digit number and it’s written on the sim900 module.

This project offers the possibility to advanced users to redirect the tracking data to another web server. Two commands control the location where HTTP POST packets are sent:

✞ | ☎

s r v your . server . com

✝ | ✆
✞ | ☎

p o r t port_number

✝ | ✆
Warning | All strings can be max 20 characters long. If you need more on any of them
please contact me.

The post request will be sent to http://your.server.com:port_number/u1. u1 has to be a CGI script (or an alias to one) that decodes the binary packets sent. See Section 4.1.2 for details.

### 3.4 SMS commands

command | ✞ | ☎

code STRING

✝ | ✆
action | pair a phone to the tracker. STRING has to be the last
4 digits of the SIM900’s IMEI
command | ✞ | ☎

gprs ?

✝ | ✆
action | show APN, USER, PASSWORD that are currently used
in order to authenticate for a gprs session
command | ✞ | ☎

setup ?

✝ | ✆
action | show a hex value containing current switches
command | ✞ | ☎

fix ?

✝ | ✆
action | try to send back a GPS fix as a SMS reply
command | ✞ | ☎

pi n g

✝ | ✆
action | a HTTP POST is sent with all available data once this command is received

command | ✞ | ☎

d e f a u l t

✝ | ✆
action | restores ALL variables to the factory defaults and re-
boots the device. the user will have to use the code command again to pair it’s phone
command | ✞ | ☎

apn STRING

✝ | ✆
default | live.vodafone.com
action | set the gprs apn value - max 20 char long in case STRING is missing, an empty apn is used
| should be set to ’net’ for an orange SIM
command | ✞ | ☎

u s e r STRING

✝ | ✆
default | live
action | set the gprs user - max 20 char long
in case STRING is missing, an empty username is used
command | ✞ | ☎

p a s s STRING

✝ | ✆
default | vodafone
action | set the gprs pass - max 20 char long in case STRING
| is missing, an empty password is used
command | ✞ | ☎

s r v STRING

✝ | ✆
default | t.subdimension.ro
action | what server to contact in order to send the tracking
| data
command | ✞ | ☎

p o r t STRING

✝ | ✆
default | 80
action | TCP port used during connection to the server
command | ✞ | ☎

v r e f STRING

✝ | ✆
default | 198
action | STRING is a number between 190 and 210 that acts as
| calibration coefficient to the on board ADC. only used
| if the voltage values reported by the module differ from
| the measured ones

command | ✞ | ☎

err ?

✝ | ✆
action | shows a hex value in case there were any errors logged
in the device. this value gets reset when all power is lost, when an ’err?’ command is replied to or after a HTTP POST packet is sent out/stored to F-RAM. only used for debug
command | ✞ | ☎

spt ?

✝ | ✆
action | shows a list of gps related timing values
command | ✞ | ☎

smt ?

✝ | ✆
action | shows a list of gprs related timing values
commands | ✞ | ☎

s p l STRING

✝ | ✆
✞ | ☎

spw STRING

✝ | ✆
✞ | ☎

s p i STRING

✝ | ✆
✞ | ☎

spg STRING

✝ | ✆
✞ | ☎

sml STRING

✝ | ✆
✞ | ☎

smst STRING

✝ | ✆
✞ | ☎

smmt STRING

✝ | ✆
action | timing variables. see section 4.1.3 for details.

### 4 Developer guide

### 4.1 Software

All the documentation, sources and hardware schematics are provided as Open Source in order to encourage further improvements by the community. The TI spy-bi-wire protocol can be used to re-flash the enclosed microcontroller.

Firmware is written in C and it’s created to be fully non-blocking and interrupt driven. The server-side scripts are in perl and bash.

Any web server can be used to receive the binary data sent from the tracker. The unpack() function present in perl, python, php will reconstruct the information and make it ready to be inserted into a database. Special care has to be taken so that the web server’s reply header is as short as possible. If it’s too long the module will not parse it properly and the data flow will be disrupted. In case nginx is used using the following settings are highly recommended:

✞ | ☎

more_clear_headers ’ Server ’;
more_clear_headers ’Date ’; more_clear_headers ’ Content - Type ’;
more_clear_headers ’ Transfer - Encoding ’;
5 | more_clear_headers ’ Connection ’;
✝ | ✆

Provided scripts have the following run time dependencies (some are optional):

- perl at least ver 5.8.2
- sqlite at least ver 3.0.0
- bash
- nginx
- fcgi

4.1.1 Tweaking the firmware

The original source code is kept in a git repository at github.com. One can grab a copy by running

✞ | ☎

git clone http :// github . com / rodan / tracy

✝ | ✆

or by downloading a snapshot archive

✞ | ☎

wget https :// github . com / rodan / tracy / archive / master . zip

✝ | ✆

compiling is as easy as

✞ | ☎

cd firmware
make clean
make
✝ | ✆

The following packages are used to compile and manage the firmware:

- msp430-gcc (ver 4.6.3 p20120406 has been used)
- msp430-binutils (2.22 p20120911)
- msp430-libc (20120716)
- msp430mcu (20120716)
- mspdebug (0.22)

Burning the firmware can be achieved with any MSP430 programmer that supports SPY-Bi-Wire.

Warning | Specialized programmers can detect the 2.8V rail the microcontroller uses and will not send signals with a higher voltage. Anything higher than 3V is just asking for trouble.
| mspdebug can be used to program the firmware:
✞ | ☎

mspdebug rf2500 " prog proj . elf "

✝ | ✆

4.1.2 HTTP POST packets

Tracking information is sent to the server by TCP packets via the HTTP POST method. A web server is thus needed to receive the data and feed it to the parsing script (see server/scripts/u1 in the repository).

In order to have a good bandwidth usage the data is sent in a binary format and the F-RAM chip that is being used allows the data to be buffered and sent out at set intervals. Most scripting languages have an unpack() function that can correctly decode these packets. A sample perl script is provided in the repository (see server/scripts/l1).

0
POST /u1 HTTP/1.0

Host: trk.subdimension.ro

Content-Type: application/binary

Content-Length: 00000

HTTP
POST
method
header

at least one subsegment

❤❤❤❤❤❤❤❤❤❤❤❤❤❤❤❤❤❤❤❤❤❤❤❤❤❤❤❤ ❤❤❤❤

❤❤❤❤

❤❤❤

❤❤❤❤

❤❤❤

❤❤❤❤

❤❤❤

❤❤❤

one
segment

Figure 1: packet format

Each positional measurement will be placed in a subsegment. At least one of these subsegments will constitute one segment that is sent out together with a HTTP header to create an HTTP POST request (see Figure 1).

Each subsegment (shown in Figure 2) has a header containing the timestamp at the time of the fix, modem IMEI, system voltages, previous errors detected, basic device configuration, an auto increment id and a byte that describes the type of the positional data. This can either be a GPS fix (Figure 3) and/or one up to four tower identification strings (Figure 4).

The tower identification strings are post-processed on the web server and a very approximate geographic position is obtained.

These subsegments are simply concatenated together to constitute the final segment being sent. The size of one such segment varies but SIM900’s internal buffering limits it up to 1000bytes. During one GPRS session one up to MAX_SEG are sent out at a time. If GPRS connections cannot be established for a long interval and MAX_SEG is reached then the oldest segment is freed in order to make place for new data.

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

4.1.3 Timings and intervals

This tracking module allows fine-grained timing customization. It can either preserve battery life for more than a month when sparse measurements are being made or it can record positional data every 10 seconds if needed. Either behavior can be set by the user via SMS commands, without the need to change the firmware.

A ’reset to factory settings’ function is also provided in case the user needs to return to known-good timing values.

Default values for the gps intervals are depicted in Table 1. The yellow time intervals are configurable: the entire loop takes 180 seconds - from which in the first 135 the gps module is powered off, a 45 sec warmup brings the device to life and it should be enough to ensure a good fix at the end of that interval. During the invalidation period the module will choose the fix with the best PDOP value and that will get stored into F-RAM.

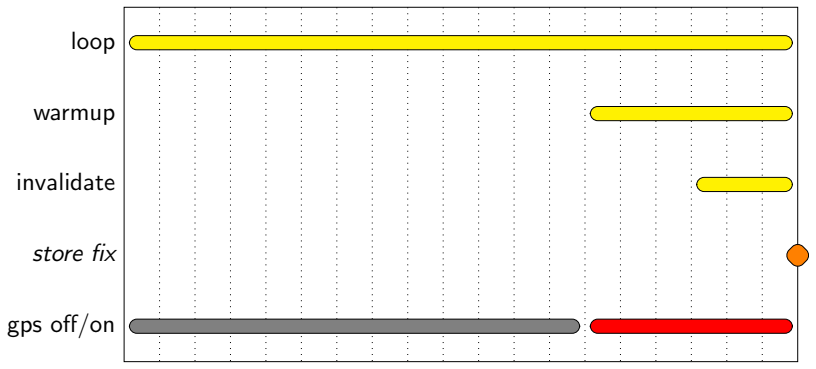
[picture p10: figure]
loop; warmup; invalidate; store fix; gps off/on

Table 1: default time intervals for the gps subsystem

If much more frequent gps data needs to be acquired, ie
loop interval ≤ warmup interval + 30s
then the gps will never be powered off. See Table 2 for an example where all gps intervals are set to 10 seconds.

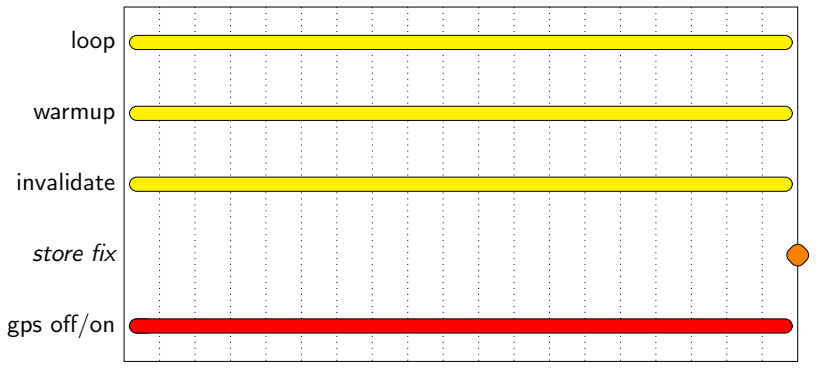
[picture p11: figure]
loop; warmup; invalidate; store fix; gps off/on

Table 2: 10s loop for the gps subsystem

As a rule of thumb try to have at least 45 seconds as the warmup interval in case the gps gets powered off. And given the fact that the gps is set to send data every two seconds to the microcontroller make sure the invalidation interval is at least 6-8 seconds.

Unlike the gps, the gsm modem needs to be kept off most of the time since it is by far the most power hungry subsystem on this module. Also a little known fact is that internet data plans have small hidden costs that can add up in time. Sometimes there is a minimum data unit (between 1-10kbytes) that gets counted for every established gprs connection, also while in roaming each gprs initialization has a cost associated with it. So depending on your gsm provider and use case, you want to get the best trade-off using the configurable variables described in this section.

The modem gets woken up by one of these two triggers:

- a periodic check for any new SMS command to be acted upon. this wake-up has no costs associated with it if no SMS reply is to be sent back to the user
trigger controlled by gprs loop interval
- upload of data stored in F-RAM via gprs. SMS commands are also accepted at this point. this trigger can happen either because enough data has piled up in the memory, one of the gprs tx intervals has been reached, the ping command was received or the module just started to move after being stationary.
trigger controlled by gprs static tx interval when the module is not moving or gprs moving tx interval otherwise.

Whatever is the reason for the modem startup, the neighboring tower cell IDs are stored as a secondary (but less precise) positioning method.

The module behavior when using the default gprs interval settings is shown in a simplified form in Table 3. Every 900 seconds the gprs loop interval wakes up the modem for a 2 minute period in which possible SMSs are parsed and tower cell IDs are captured.

A movement that was detected triggers an upload of data and makes the next upload happen after 600sec (gprs moving tx interval). The next transfer will happen after 3600sec (gprs static tx interval) since the module is not moving.

loop trigger
movement
tx trigger

Table 3: default module behavior

4.1.4 List of timing variables

gps loop interval | value | unit min | default | max
value | 10 | 180 | 65535 | seconds
sms command to set | spl value
sms command to view | spt?
description | sets the interval between two gps measurement sessions
gps warmup interval | value | unit min | default | max
value | 0 | 45 | 65535 | seconds
sms command to set | spw value
sms command to view | spt?
description | time interval between gps powerup and the ac-tual measurement

gps invalidate interval | value | unit min | default | max
value | 0 | 20 | 65535 | seconds
sms command to set | spi value
sms command to view | spt?
description | time interval at the end of the measurement session during which the gps fix with the best PDOP is searched for

spi must be a smaller value then spl.

gps geofence trigger | value | unit min | default | max
value | 0 | 300 | 65535 | meters
sms command to set | spg value
sms command to view | spt?
description | minimal distance between two consecutive fixes at which the device is considered non-stationary

Heavy cloud coverage or large adjacent buildings can obscure or create multipath errors in the gps signal detection. It is thus advisable to not set the spg variable too low in order to minimize false-positives.

gprs loop interval | value | unit min | default | max
value | 180 | 900 | 65535 | seconds
sms command to set | sml value
sms command to view | smt?
description | time interval between two gsm connection at-tempts (these are used to get tower id data and to receive and parse sms commands)

each application needs a different trade-off between sms responsiveness and low power consumption.

gprs static tx interval | value | unit min | default | max
value | 180 | 3600 | 65535 | seconds
sms command to set | smst value
sms command to view | smt?
description | time interval between two HTTP POSTs when the device is stationary (see spg 4.1.4)
gprs moving tx interval | value | unit min | default | max
value | 180 | 600 | 65535 | seconds
sms command to set | smmt value
sms command to view | smt?
description | time interval between two HTTP POSTs when the device is moving (see spg 4.1.4)

all the timings in this section are used for scheduling the respective actions. the final timestamps received in the web reports will not follow exactly the values entered. this happens because the device tries to get the best fix possible in the spi interval based on PDOP measurements and also because most actions performed are dependent on both outside factors (how quickly a good fix is received from the gps, mobile service availability, how many sms actions need to be executed) as well as local interactions (the gprs modem can only perform one task at any given time).

### 4.2 Hardware

4.2.1 Absolute maximum ratings

| value | unit
min | max
VI | input voltage | IN (with respect to VSS) | -0.3 | 28 | V
| | VBAT (with respect to VSS) | -0.3 | 5 | V
VIO | IO voltage thru the debug connector | | -0.3 | 3.1 | V
Tstg | storage temperature | | -65 | 150 | ◦C
Top | operating temperature | | 0 | 125 | ◦C

Stresses above those listed in absolute maximum ratings may cause permanent damage to the device. This is a stress rating only, functional operation of the device at these or any other conditions above those indicated in the operational section of this specification is not implied. Exposure to absolute maximum rating conditions for extended periods may affect device reliability.

4.2.2 Electrical characteristics

| value | unit
min | typ | max
VI | input voltage range | 4.35 | 5 | 6.4 | V
II | input current | X | X | 1.5 | A
VBAT | battery voltage range | 3.5 | | 4.1 | V
IBAT | battery current on sim900 poweron | | | 3200 | mA
IBAT | battery current while sim900 tx | | | 1600 | mA
IBAT | battery current while gps on | | 25 | 45 | mA
IBAT | battery current while sleeping | 70 | | 75 | µA
ICHG | battery charging current 1 | | 0.3 | | A
VIO | IO voltage thru the debug connector | 0 | | 2.8 | V

4.2.3 Components

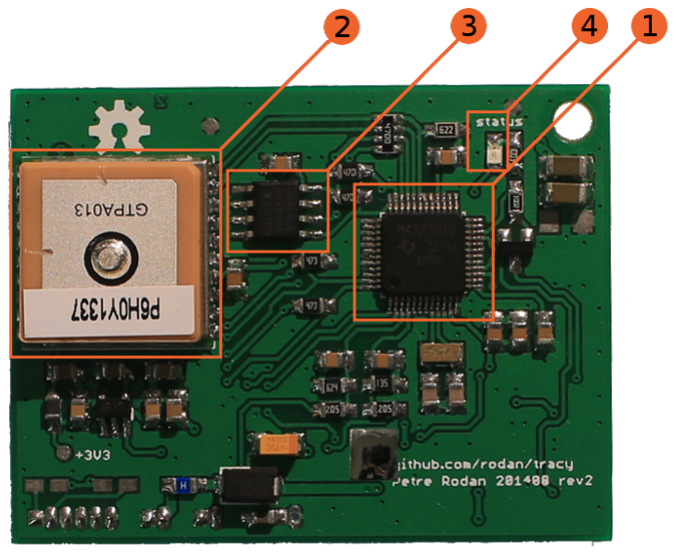
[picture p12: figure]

1 MSP430F5510 mixed
signal microcontroller

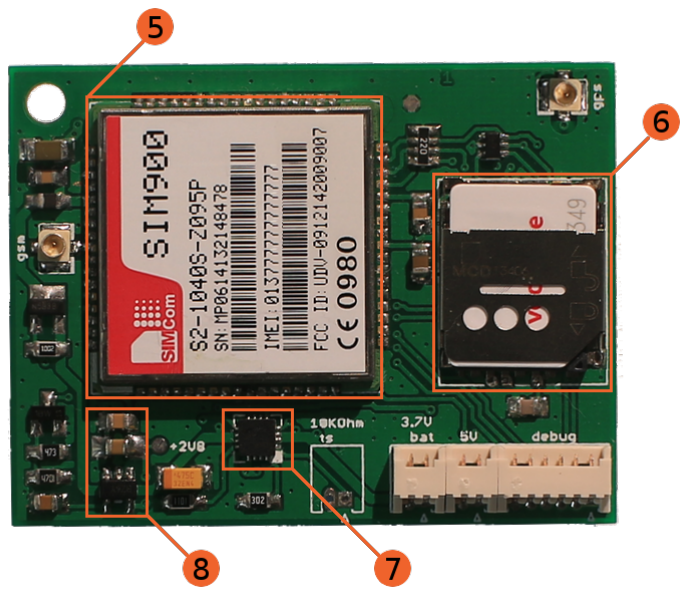
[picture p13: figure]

- 16bit RISC architecture with 32KB flash and 4KB of SRAM

1The charging current is configurable by changing the value of R11. See the module schematic and the bq24072 datasheet for details

- low supply voltage - 2.8V used in this implementation
- ultra-low power consumption
- 10bit ADC - both the battery voltage and input voltage levels are kept in check
- 4 16bit timers with interrupt generation - used to synchronize all processes
- real-time clock - keeps calendar data and the clock when gps signal is missing
- port mapping controller - allows digital functions to be switched between different ports
- watchdog, brown out reset - ensures the system runs in stable parameters

2 MT3339 MediaTek GPS
chipset
- tiny gps module that can track 22 satellites at any given moment
- even if the module is mostly shut down to conserve power, the backup voltage is always provided thus ensuring a fast time-to-fix when started up
- automatic antenna switching detects external antennas

3 FM24CL64B-G F-RAM
IC
- additional 8kbytes of F-RAM for data buffering and storage

4 status LED

- very high efficiency LED that uses 28 µA while lit
- very faint blips every two seconds while gps is on and there is no usable gps signal
- less faint blips every two seconds while gps is on and gps signal is fine
- full brightness for 2 seconds while modem powers up

5 SIM900 quad-band
GSM/GPRS engine
- GSM 850MHz, EGSM 900MHz, DCS 1800MHz, PCS 1900MHz frequencies are supported
- a dedicated user-provided micro SIM is needed to connect to the mobile phone network of choice. M2M SIMs also work since voice is never used in this application.

6 SIM card MICRO form factor SIM card holder

7 BQ24072 power path
management IC | • allows charging of the Li-Ion/LiPo cell from a USB friendly 5V source
| • maximum charging current is limited to 300mA
8 2.8V rail | the only power rail that remains on during microcontroller standby inter- vals. it can be used to power low voltage sensors/accelerometers/etc via the programming connector.

4.2.4 Connectors

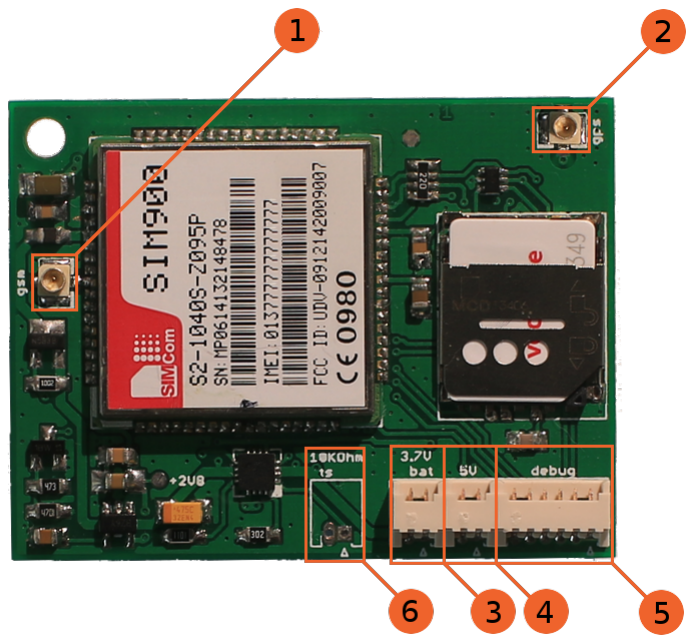
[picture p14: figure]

for all pin connectors, pin 1 is marked by a small triangle in the silkscreen

1 gsm antenna
connector | UFL
silkscreen | gsm
use | it is mandatory to connect the enclosed antenna via this connector

pin assignments
shroud | GND
center | signal

2 gps antenna
connector | UFL
silkscreen | gps
use | the gps module provides a small patch antenna but one could improve signal reception by using an external one connected here

pin assignments
shroud | GND
center | signal

3 LiPo/Li-Ion 1 cell battery
connector footprint | Molex 053048-0210
silkscreen | 3.7V bat
use | 1 cell (3.7V) rechargeable Li-Ion or Li polymer battery
pin assignments
1 | GND
2 | +3.7V

4 5V DC input
connector footprint | Molex 053048-0210
silkscreen | 5V
use | 5V DC either from a USB connection or a DCDC con-verter. used only to charge the included battery with a current up to 300mA

pin assignments
1 | GND
2 | +5V

5 programming/debug connector
connector footprint | Molex 053048-0610
silkscreen | debug
use | pins 3-6 are used for TI’s spy-bi-wire protocol in order to program or to debug the microcontroller. pins 1 and 2 can have a custom assignation

pin assignments
1 | P4.1 - context dependent microcontroller port
2 | P4.0 - context dependent microcontroller port
3 | 2.8V - VCC OUT
4 | TEST
5 | RST
6 | GND

6 battery thermistor
connector footprint | Molex 053048-0210
silkscreen | 10KOhm ts
use | some battery packs provide this component as a charge ending protection. by default this connector is unpopu-lated and if it’s use is required the 10K resistor located on the other side of the PCB needs to be removed

pin assignments
1 | 10K NTC thermistor
2 | 10K NTC thermistor (also GND)
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

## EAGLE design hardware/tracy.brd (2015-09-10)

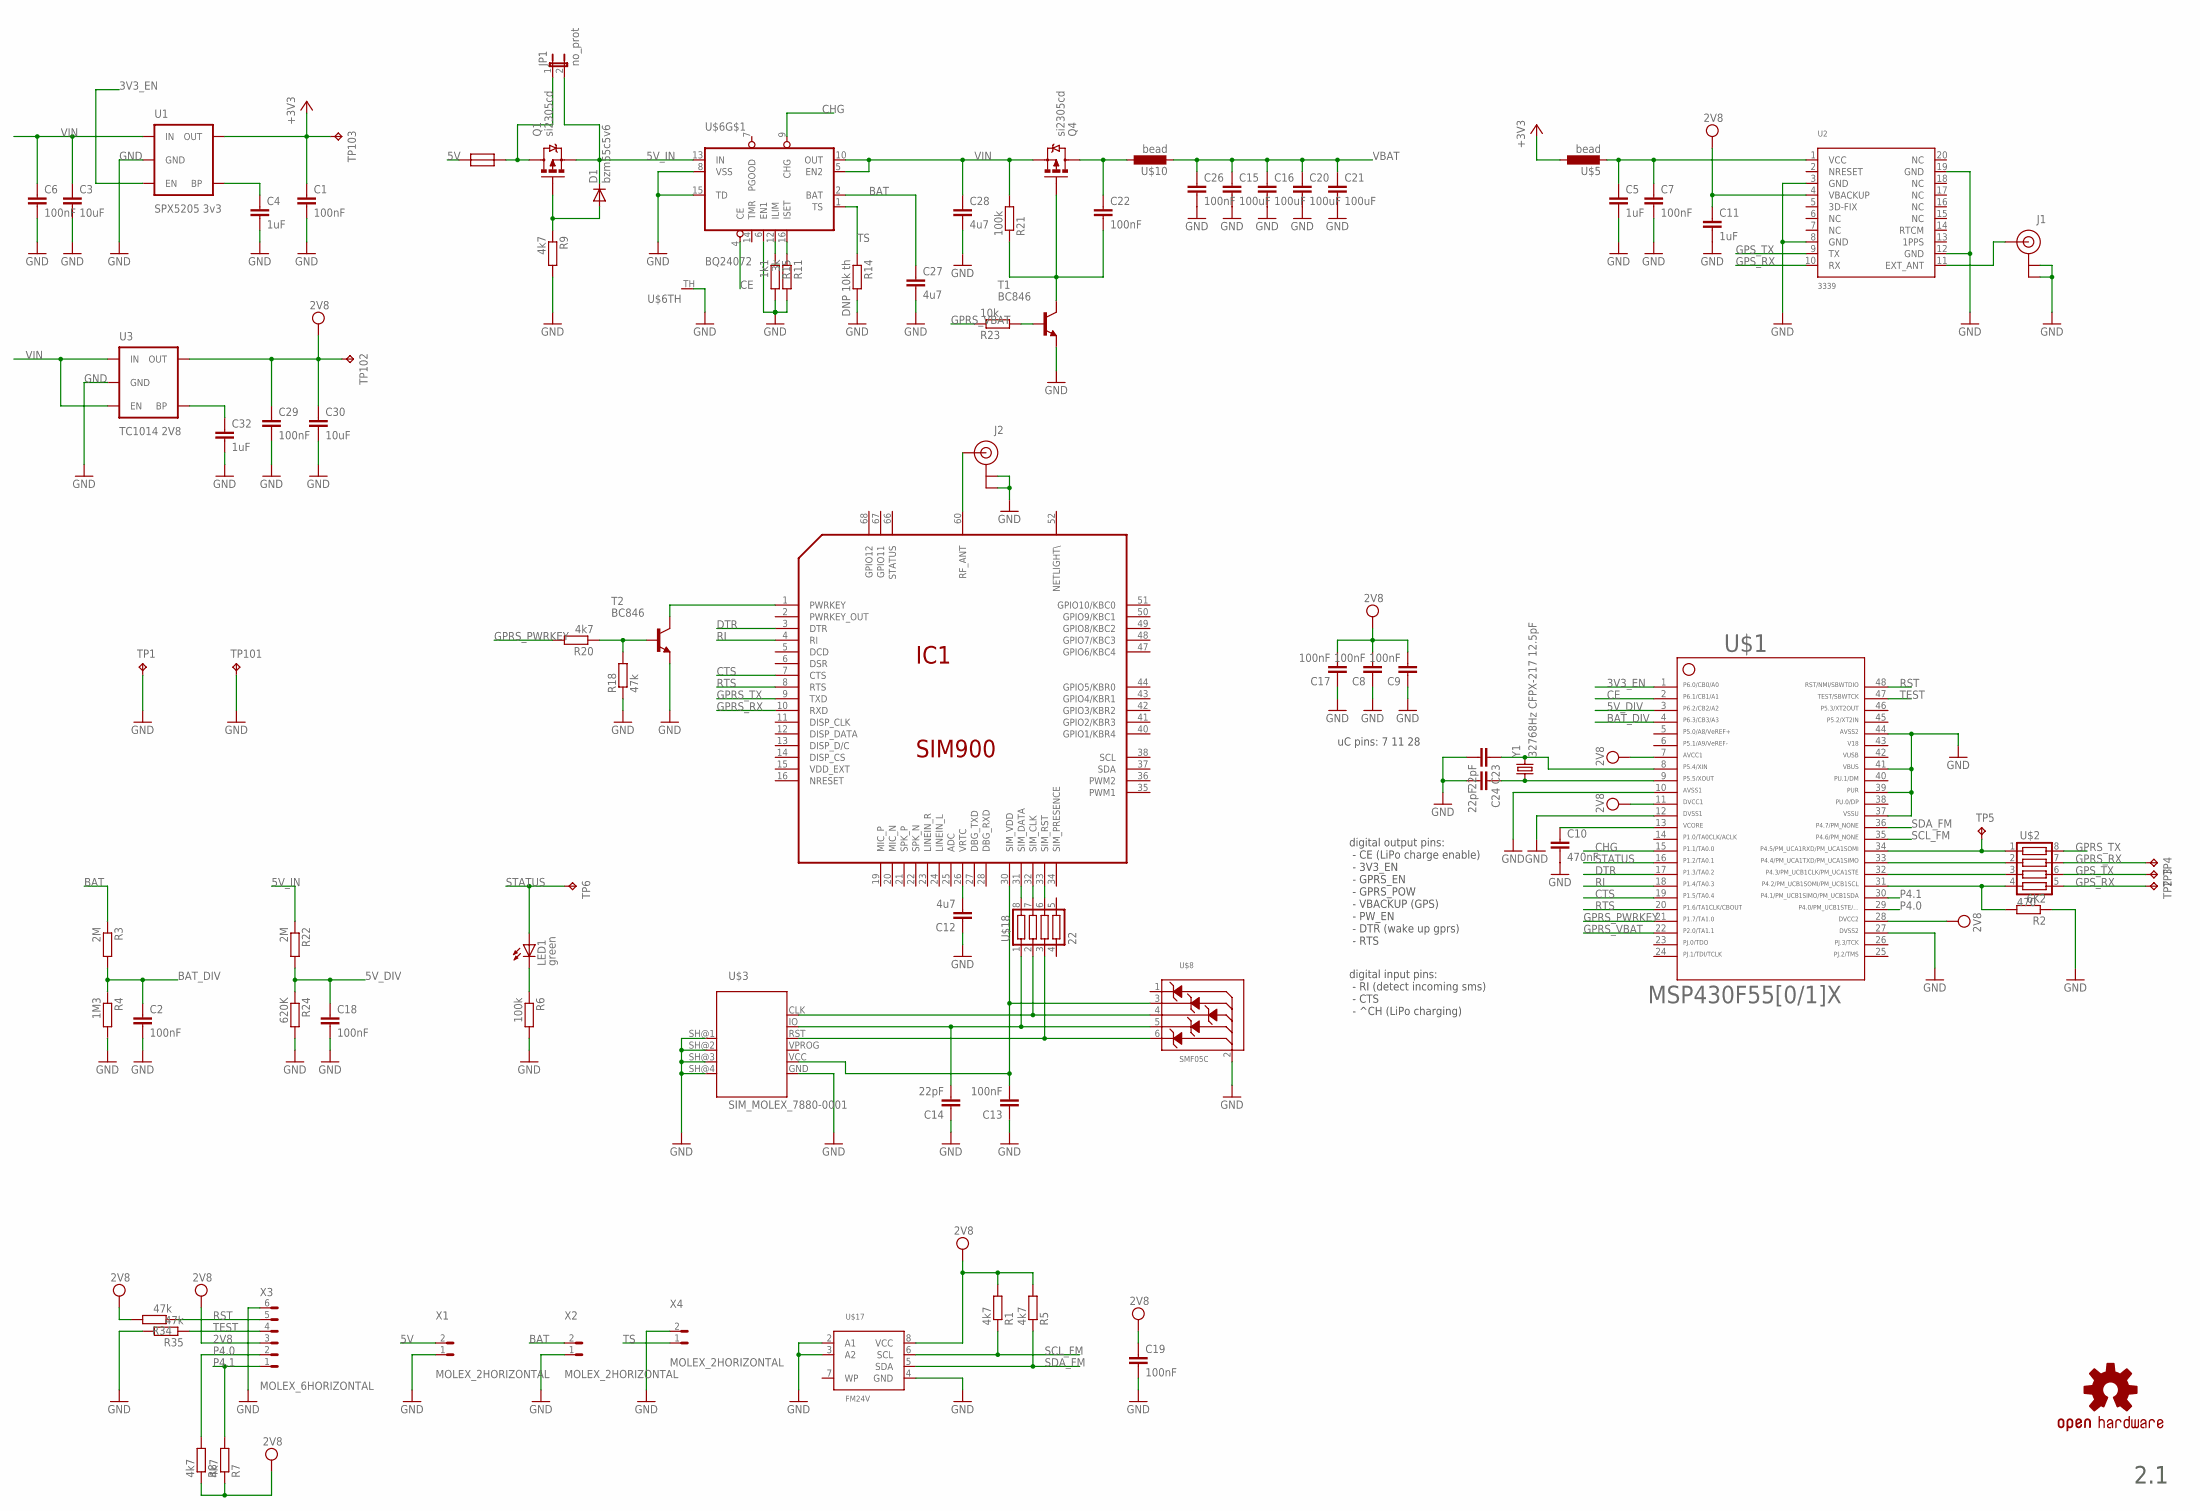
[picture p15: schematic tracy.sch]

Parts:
C1, C2, C6, C7, C8, C9, C13, C17, C18, C19, C22, C26, C29: 100nF; C0805
C3: 10uF; C0805
C4, C5, C11, C32: 1uF; C0805
C10: 470nF; C0805
C12: 4u7; C0805
C14, C23, C24: 22pF; C0805
C15, C16, C20, C21: 100uF; C1206
C27, C28: 4u7; C1206
C30: 10uF; C1206
D1: bzm55c5v6; MICROMELF-W
IC1: SIM900
J1, J2: U.FL
JP1: no_prot; SJ_2S-NO
LED1: green; CHIPLED_0805
Q1, Q4: si2305cd; SOT23-3_POWER
R1, R5, R7, R8, R9, R20: 4k7; R0805W
R2: 6K2; R0805W
R3, R22: 2M; R0805W
R4: 1M3; R0805W
R6, R21: 100k; R0805W
R11: 3k; R0805W
R14: DNP 10k th; R0805W
R15: 1k1; R0805W
R18, R34, R35: 47k; R0805W
R23: 10k; R0805W
R24: 620K; R0805W
T1, T2: BC846; SOT23
TP1, TP2, TP3, TP4, TP5, TP6, TP101, TP102, TP103: TPTP12R; TP12R
U1: SPX5205 3v3; SOT23-5
U2: 3339; FGPMMOPA6H
U3: TC1014 2V8; SOT23-5
U$1: MSP430F5510; PT48
U$2: 470; YC164
U$3: SIM_MOLEX_7880-0001; MOLEX_7880-0001
U$5, U$10: bead; L0805W
U$6: BQ24072; S-PVQFN-N16
U$7: OSHW-LOGOM; OSHW-LOGO-M
U$8: SMF05C; SC-88
U$9: RESETTABLE_0805; 0805W
U$17: FM24V; SO-08
U$18: 22; YC164
X1, X2, X4: MOLEX_2HORIZONTAL; 0530480210
X3: MOLEX_6HORIZONTAL; 0530480610
Y1: 32768Hz CFPX-217 12.5pF; CRYSTAL-SMD-3.2X1.5

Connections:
2V8: C8.2, C9.2, C11.1, C17.2, C19.1, C29.1, C30.1, R1.2, R5.2, R7.1, R8.1, R34.2, TP102.TP, U2.4 (VBACKUP), U3.5 (OUT), U$1.7, U$1.11, U$1.28, U$17.8 (VCC), X3.3 (4)
3V3_EN: U1.3 (EN), U$1.1
5V: U$9.1, X1.2 (1)
5V_DIV: C18.1, R22.2, R24.1, U$1.3
5V_IN: D1.C, JP1.2, Q1.2 (S), R22.1, U$6.13 (IN)
42: U$1.42
43: U$1.43
46: U$1.46
+3V3: C1.1, TP103.TP, U1.5 (OUT), U$5.1
BAT: C27.1, R3.1, U$6.2 (BAT), X2.2 (1)
BAT_DIV: C2.1, R3.2, R4.1, U$1.4
CE: U$1.2, U$6.4 (CE)
CHG: U$1.15, U$6.9 (CHG)
CTS: IC1.7 (CTS), U$1.19
DTR: IC1.3 (DTR), U$1.17
GND: C1.2, C2.2, C3.2, C4.2, C5.2, C6.2, C7.2, C8.1, C9.1, C10.2, C11.2, C12.1, C13.1, C14.1, C15.2, C16.2, C17.1, C18.2, C19.2, C20.2, C21.2, C23.2, C24.2, C26.2, C27.2, C28.2, C29.2, C30.2, C32.2, IC1.17 (GND), IC1.18 (GND), IC1.29 (GND), IC1.39 (GND), IC1.45 (GND), IC1.46 (GND), IC1.53 (GND), IC1.54 (GND), IC1.58 (GND), IC1.59 (GND), IC1.61 (GND), IC1.62 (GND), IC1.63 (GND), IC1.64 (GND), IC1.65 (GND), J1.P$1 (GND), J1.P$2 (GND), J2.P$1 (GND), J2.P$2 (GND), R2.1, R4.2, R6.2, R9.2, R11.2, R14.2, R15.2, R18.1, R24.2, R35.2, T1.2 (E), T2.2 (E), TP1.TP, TP101.TP, U1.2 (GND), U2.3 (GND), U2.8 (GND), U2.12 (GND), U2.19 (GND), U3.2 (GND), U$1.10, U$1.12, U$1.27, U$1.37, U$1.39, U$1.41, U$1.44, U$3.GND, U$3.SH@1 (SH), U$3.SH@2 (SH), U$3.SH@3 (SH), U$3.SH@4 (SH), U$6.6 (EN1), U$6.8 (VSS), U$6.15 (TD), U$6.TH, U$8.2 (ANODE), U$17.2 (A1), U$17.3 (A2), U$17.4 (GND), X1.1 (2), X2.1 (2), X3.6 (1), X4.2 (1)
GPRS_PWRKEY: R20.2, U$1.21
GPRS_RX: IC1.10 (RXD), TP4.TP, U$2.7
GPRS_TX: IC1.9 (TXD), U$2.8
GPRS_VBAT: R23.1, U$1.22
GPS_RX: TP2.TP, U2.10 (RX), U$2.5
GPS_TX: TP3.TP, U2.9 (TX), U$2.6
GPS_VCC: C5.1, C7.1, U2.1 (VCC), U$5.2
unnamed: U$1.32, U$2.3
unnamed: C4.1, U1.4 (BP)
unnamed: R2.2, U$1.31, U$2.4
unnamed: U$1.33, U$2.2
unnamed: JP1.1, Q1.3 (D), U$9.2
unnamed: C10.1, U$1.13
unnamed: R23.2, T1.1 (B)
unnamed: LED1.C, R6.1
unnamed: J1.P$3 (SIGNAL), U2.11 (EXT_ANT)
unnamed: TP5.TP, U$1.34, U$2.1
unnamed: D1.A, Q1.1 (G), R9.1
unnamed: IC1.31 (SIM_DATA), U$18.8
unnamed: IC1.32 (SIM_CLK), U$18.7
unnamed: IC1.33 (SIM_RST), U$18.6
unnamed: C24.1, U$1.9, Y1.P$1 (1)
unnamed: C23.1, U$1.8, Y1.P$2 (2)
unnamed: R11.1, U$6.16 (ISET)
unnamed: R15.1, U$6.12 (ILIM)
unnamed: R18.2, R20.1, T2.1 (B)
unnamed: IC1.60 (RF_ANT), J2.P$3 (SIGNAL)
unnamed: C22.2, Q4.1 (G), R21.1, T1.3 (C)
unnamed: C22.1, Q4.3 (D), U$10.1
unnamed: C32.1, U3.4 (BP)
P4.0: R8.2, U$1.29, X3.2 (5)
P4.1: R7.2, U$1.30, X3.1 (6)
PWRKEY: IC1.1 (PWRKEY), T2.3 (C)
RI: IC1.4 (RI), U$1.18
RST: R34.1, U$1.48, X3.5 (2)
RTS: IC1.8 (RTS), U$1.20
SCL_FM: R1.1, U$1.35, U$17.6 (SCL)
SDA_FM: R5.1, U$1.36, U$17.5 (SDA)
SIMLOCK_CLK: U$3.CLK, U$8.4 (CATODE3), U$18.2
SIMLOCK_IO: C14.2, U$3.IO, U$8.5 (CATODE4), U$18.1
SIMLOCK_RST: U$3.RST, U$8.6 (CATODE5), U$18.3
SIM_VCC: C13.2, IC1.30 (SIM_VDD), U$3.VCC, U$8.3 (CATODE2)
STATUS: LED1.A, TP6.TP, U$1.16
TEST: R35.1, U$1.47, X3.4 (3)
TS: R14.1, U$6.1 (TS), X4.1 (2)
VBAT: C15.1, C16.1, C20.1, C21.1, C26.1, IC1.55 (VBAT), IC1.56 (VBAT), IC1.57 (VBAT), U$10.2
VIN: C3.1, C6.1, C28.1, Q4.2 (S), R21.2, U1.1 (IN), U3.1 (IN), U3.3 (EN), U$6.5 (EN2), U$6.10 (OUT)
VRTC: C12.2, IC1.26 (VRTC)

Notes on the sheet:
2.1
uC pins: 7 11 28
digital output pins: - CE (LiPo charge enable) - 3V3_EN - GPRS_EN - GPRS_POW - VBACKUP (GPS) - PW_EN - DTR (wake up gprs) - RTS
digital input pins: - RI (detect incoming sms) - CTS - ^CH (LiPo charging)

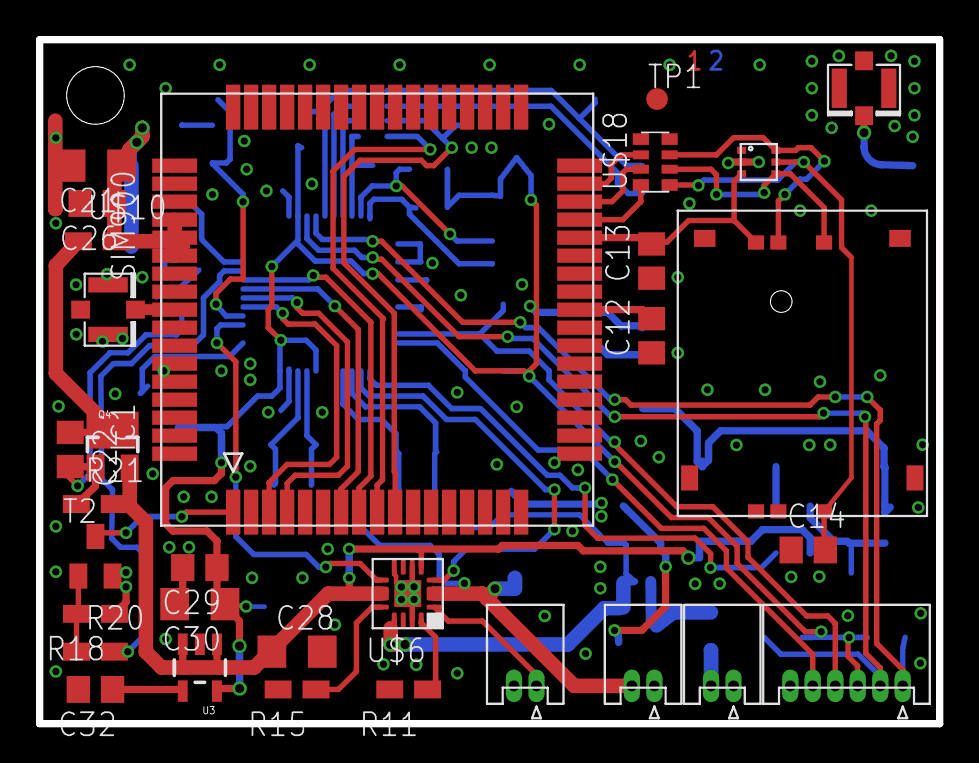
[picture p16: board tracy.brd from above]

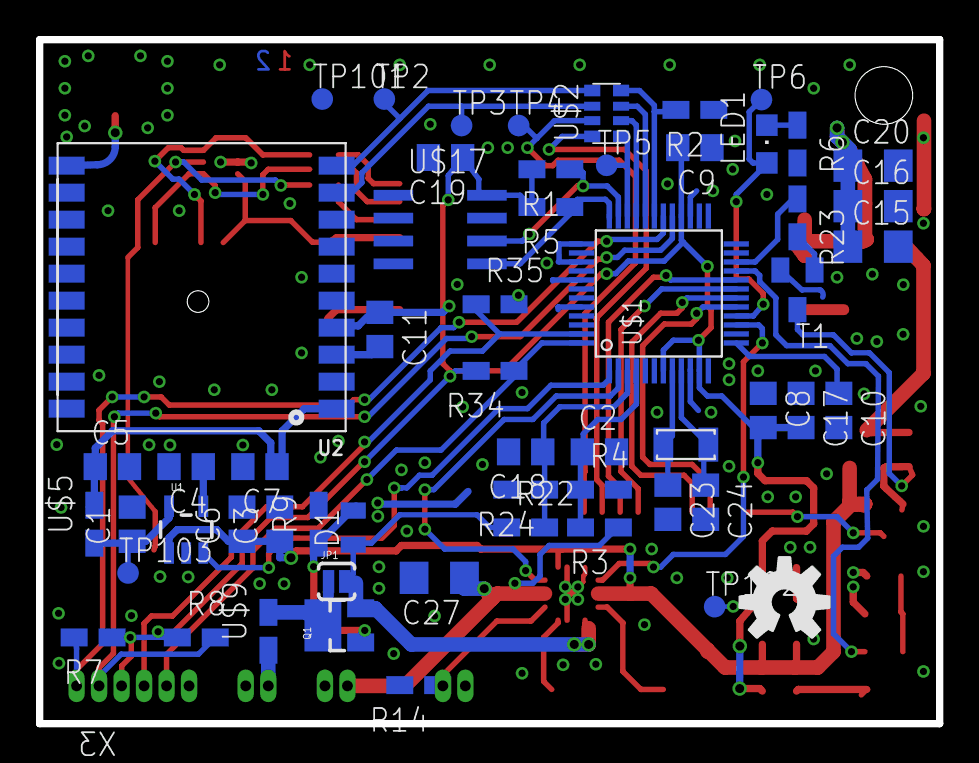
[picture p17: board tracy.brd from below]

Board: 2 copper layers, 50.0 x 38.0 mm, 88 parts (57 on the bottom side), 61 nets.

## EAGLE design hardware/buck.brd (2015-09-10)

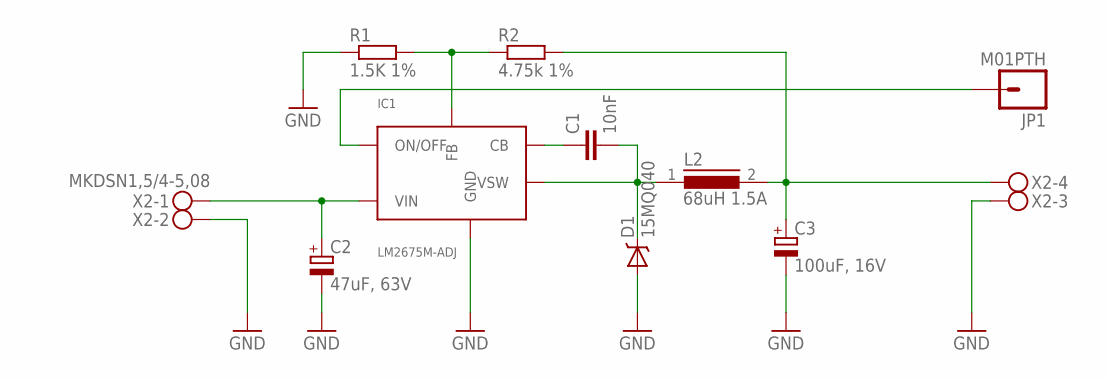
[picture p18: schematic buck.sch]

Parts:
C1: 10nF; C0805
C2: 47uF, 63V; PANASONIC_F
C3: 100uF, 16V; PANASONIC_D
D1: 15MQ040; SMA-DIODE
IC1: LM2675M-ADJ; SO-08
JP1: M01PTH; 1X01
L2: 68uH 1.5A; DR125
R1: 1.5K 1%; R0805W
R2: 4.75k 1%; R0805W
X2: MKDSN1,5/4-5,08

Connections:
GND: C2.-, C3.-, D1.A, IC1.6 (GND), R1.1, X2.2, X2.3
unnamed: IC1.4 (FB), R1.2, R2.1
unnamed: C1.2, D1.C, IC1.8 (VSW), L2.1
unnamed: C1.1, IC1.1 (CB)
unnamed: C3.+, L2.2, R2.2, X2.4
unnamed: IC1.5 (ON/OFF), JP1.1
unnamed: C2.+, IC1.7 (VIN), X2.1

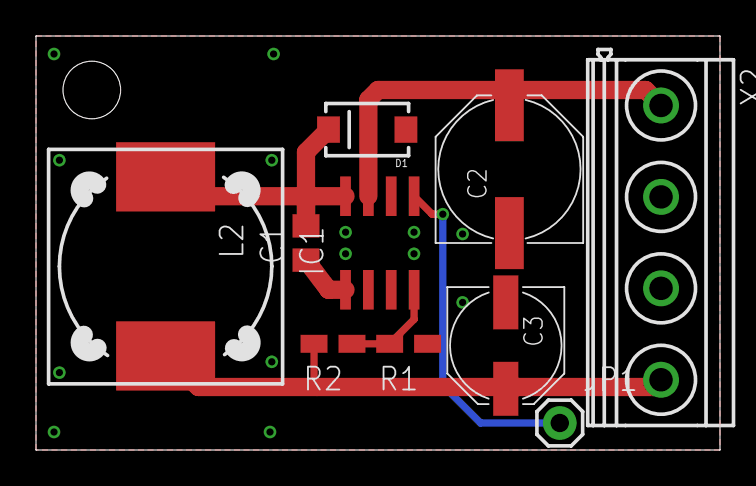
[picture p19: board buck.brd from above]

Board: 2 copper layers, 38.0 x 23.0 mm, 10 parts (0 on the bottom side), 7 nets.

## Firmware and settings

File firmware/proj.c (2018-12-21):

//  GPS/GPRS tracking system based on a MSP430F5510 uC
//
//  author:          Petre Rodan <2b4eda@subdimension.ro>
//  available from:  https://github.com/rodan/
//  license:         GNU GPLv3

#include <stdio.h>
#include <string.h>

#include "proj.h"
#include "drivers/sys_messagebus.h"
#include "drivers/rtc.h"
#include "drivers/timer_a0.h"
#include "drivers/uart0.h"
#include "drivers/uart1.h"
#include "drivers/adc.h"
#include "drivers/gps.h"
#include "drivers/sim900.h"
#include "drivers/flash.h"
#include "drivers/fm24.h"
#include "drivers/fm24_memtest.h"
#include "qa.h"

#define GPSMAX 255

const char gps_init[] = "$PMTK314,0,2,0,0,2,0,0,0,0,0,0,0,0,0,0,0,0,0,0*28\r\n";

uint32_t rtca_set_next = 0;

uint32_t status_show_next = 0;

uint32_t adc_check_next = 0;
uint16_t adc_check_interval = 15;

uint32_t gps_reinit_next = 0;
uint16_t gps_reinit_interval = 120;

uint32_t movement_next = 0;

#ifndef DEBUG_GPRS
static void parse_gps(enum sys_message msg)
{
    nmea_parse((char *)uart0_rx_buf, uart0_p);

    uart0_p = 0;
    uart0_rx_enable = 1;
    LED_OFF;
}
#endif

#ifndef DEBUG_GPS
static void parse_gprs(enum sys_message msg)
{
#ifdef DEBUG_GPRS
    uart0_tx_str((char *)uart1_rx_buf, uart1_p);
#endif
    sim900_parse_rx((char *)uart1_rx_buf, uart1_p);
}
#endif

#ifdef DEBUG_GPRS
static void parse_UI(enum sys_message msg)
{
    parse_user_input();

    uart0_p = 0;
    uart0_rx_enable = 1;
    LED_OFF;
}
#else

static void schedule(enum sys_message msg)
{

    // battery related
    if (rtca_time.sys > adc_check_next) {
        adc_read();

        adc_check_next = rtca_time.sys + adc_check_interval;

        if ((stat.v_raw > 400) && (stat.v_raw < 550)) {
            if (CHARGING_STOPPED) {
                if (stat.should_charge) {
                    CHARGE_DISABLE;
                    stat.should_charge = false;
                    adc_check_next = rtca_time.sys + 300;
                } else {
                    if (stat.v_bat < 390) {
                        CHARGE_ENABLE;
                        stat.should_charge = true;
                        charge_start = rtca_time.sys;
                    }
                }
            } else {
                if (rtca_time.sys > charge_start + 36000) {
                    CHARGE_DISABLE;
                    stat.should_charge = false;
                    adc_check_next = rtca_time.sys + 3600;
                }
            }
        } else {
            CHARGE_DISABLE;
            stat.should_charge = false;
        }
    }

    // GPS related
    if (rtca_time.sys > gps_trigger_next) {

        switch (gps_next_state) {
            case MAIN_GPS_IDLE:
                if (s.gps_loop_interval > s.gps_warmup_interval + 30) {
                    // when gps has OFF intervals
                    gps_disable();
                    gps_trigger_next = rtca_time.sys + s.gps_loop_interval - s.gps_warmup_interval - 2;
                }
                gps_next_state = MAIN_GPS_START;
            break;
    
            case MAIN_GPS_START:
                gps_next_state = MAIN_GPS_INIT;
                gps_enable();
            break;

            case MAIN_GPS_INIT:
                if (s.gps_loop_interval > s.gps_warmup_interval + 30) {
                    // gps had a power off interval
                    gps_trigger_next = rtca_time.sys + s.gps_warmup_interval - s.gps_invalidate_interval - 3;
                    uart0_tx_str((char *)gps_init, 51);
                } else {
                    // gps was on all the time
                    gps_trigger_next = rtca_time.sys + s.gps_loop_interval - s.gps_invalidate_interval - 3;
                    if (rtca_time.sys > gps_reinit_next) {
                        gps_reinit_next = rtca_time.sys + gps_reinit_interval;
                        uart0_tx_str((char *)gps_init, 51);
                    }
                }
                gps_next_state = MAIN_GPS_PDOP_RST;
                // zero out all the old data
                memset(&mc_f, 0, sizeof(mc_f));
            break;
    
            case MAIN_GPS_PDOP_RST:
                gps_trigger_next = rtca_time.sys + s.gps_invalidate_interval - 1;
                gps_next_state = MAIN_GPS_STORE;
                mc_f.pdop = 9999;
            break;
    
            case MAIN_GPS_STORE:
                if (mc_f.fix) {
                    // save all info to f-ram
                    store_pkt();
                }
                gps_next_state = MAIN_GPS_IDLE;
            break;
        }
    }

    // GPRS related
    // force the HTTP POST from time to time
    if (rtca_time.sys > gprs_tx_next) {
        if (gprs_tx_trig & TG_NOW_MOVING) {
            gprs_tx_next = rtca_time.sys + s.gprs_moving_tx_interval;
        } else {
            gprs_tx_next = rtca_time.sys + s.gprs_static_tx_interval;
        }
        sim900.flags |= TX_FIX_RDY;
    }

    if (sim900.flags & BLACKOUT) {
       if (rtca_time.sys > gprs_blackout_lift) {
           sim900.flags &= ~BLACKOUT;
       }
    }

    if (((rtca_time.sys > gprs_trigger_next) || (sim900.flags & TX_FIX_RDY)) && 
            !(sim900.flags & TASK_IN_PROGRESS)) {

        // time to act
        adc_read();
        gprs_trigger_next = rtca_time.sys + s.gprs_loop_interval;

        if (stat.v_bat > 350) {
#ifndef DEBUG_GPS
            // if battery voltage is below ~3.4v
            // the sim will most likely lock up while trying to TX
            if (!(sim900.flags & BLACKOUT)) {
                sim900_exec_default_task();
            }
#endif
        }
    }
}
#endif

int main(void)
{
    main_init();
    rtca_init();
    timer_a0_init();
    uart0_init();
    sim900_init_messagebus();
    sim900.next_state = SIM900_OFF;

    settings_init(SEGMENT_B, VERSION_BASED);
    //settings_apply();

    m.e = 0x0;
    m.seg[0] = 0x0;
    m.seg_num = 1;

    stat.http_post_version = POST_VERSION;
    stat.fix_id = 1;

    sim900.imei[0] = 0;
    sim900.flags = 0;


    gps_trigger_next = 0;
    gprs_trigger_next = s.gprs_loop_interval;

    rtca_set_next = 0;
    rtc_not_set = 1;
    gps_next_state = MAIN_GPS_IDLE;

    if (s.gps_invalidate_interval > s.gps_loop_interval) {
        s.gps_invalidate_interval = s.gps_loop_interval;
    }
   
    gprs_tx_trig = 0;
    gprs_tx_next = s.gprs_static_tx_interval;

    gprs_blackout_lift = 0;

#ifdef DEBUG_GPS
    uart1_init(9600);
    uart1_tx_str("gps debug state\r\n", 17);
#endif

#ifdef DEBUG_GPRS
    uart0_tx_str("gprs debug state\r\n", 18);
    display_menu();
#endif

#ifdef CALIBRATION
    sys_messagebus_register(&adc_calibration, SYS_MSG_RTC_SECOND);
#else
#ifndef DEBUG_GPRS
    sys_messagebus_register(&schedule, SYS_MSG_RTC_SECOND);
    sys_messagebus_register(&parse_gps, SYS_MSG_UART0_RX);
#else
    sys_messagebus_register(&parse_UI, SYS_MSG_UART0_RX);
#endif
#ifndef DEBUG_GPS
    sys_messagebus_register(&parse_gprs, SYS_MSG_UART1_RX);
#endif

#endif

#ifdef FM24_HAS_SLEEP_MODE
    fm24_sleep();
#endif

    // main loop
    while (1) {
        _BIS_SR(LPM3_bits + GIE);
        //wake_up();
#ifdef USE_WATCHDOG
        // reset watchdog counter
        WDTCTL = (WDTCTL & 0xff) | WDTPW | WDTCNTCL;
#endif
        // new messages can be sent from within a check_events() call, so 
        // parse the message linked list multiple times
        check_events();
        check_events();
        check_events();

#ifdef FM24_HAS_SLEEP_MODE
        // sleep
        if (fm24_status & FM24_AWAKE) {
            fm24_sleep();
        }
#endif

        // P4.0 and P4.1
        //P4SEL &= ~0x3;
        
        /*
        PMMCTL0_H = 0xA5;
        SVSMHCTL &= ~SVMHE;
        SVSMLCTL &= ~(SVSLE+SVMLE);
        PMMCTL0_H = 0x00;
        */
    }
}

void main_init(void)
{

    // watchdog triggers after 4 minutes when not cleared
#ifdef USE_WATCHDOG
    WDTCTL = WDTPW + WDTIS__8192K + WDTSSEL__ACLK + WDTCNTCL;
#else
    WDTCTL = WDTPW + WDTHOLD;
#endif
    //SetVCore(3);

    // enable LF crystal
    P5SEL |= BIT5 + BIT4;
    UCSCTL6 &= ~(XT1OFF | XT1DRIVE0);

    P1SEL = 0x0;
    P1OUT = 0x2;
    P1DIR = 0x85;
    //P1REN = 0x2;
    // make sure CTS is pulled low so the software doesn't get stuck 
    // in case the sim900 is missing - or broken.
    P1REN = 0x22;

    P2SEL = 0x0;
    P2OUT = 0x0;
    P2DIR = 0x1;

    P3SEL = 0x0;
    P3OUT = 0x0;
    P3DIR = 0x1f;

    P4OUT = 0x0;
    //P4DIR = 0x00;
    P4DIR = 0x3;

    PMAPPWD = 0x02D52;
    // set up UART port mappings

    // there is only one debug uart on (P4.1, P4.0)
    // so we either leave out the gps (P4.2, P4.3) or the gprs (P4.4, P4.5) module

#ifdef DEBUG_GPRS
    // debug interface
    P4MAP1 = PM_UCA0TXD;
    P4MAP0 = PM_UCA0RXD;
    P4SEL |= 0x3;
#else
    // enable GPS module
    P4MAP2 = PM_UCA0TXD;
    P4MAP3 = PM_UCA0RXD;
#endif

    // try to also send uart0 tx to 4.1 XXX
    //P4MAP1 = PM_UCA0TXD;
    //P4SEL |= 0x2;

#ifdef DEBUG_GPS
    // debug interface
    P4MAP1 = PM_UCA1TXD;
    P4MAP0 = PM_UCA1RXD;
    P4SEL |= 0x3;
#endif
    PMAPPWD = 0;

    P5OUT = 0x0;
    //P5SEL is set above
    P5DIR = 0xf;

    P6SEL = 0xc;
    P6OUT = 0x2;
    P6DIR = 0x3;

    PJOUT = 0x00;
    PJDIR = 0xFF;

    // disable VUSB LDO and SLDO
    USBKEYPID = 0x9628;
    USBPWRCTL &= ~(SLDOEN + VUSBEN);
    USBKEYPID = 0x9600;

}

void check_events(void)
{
    struct sys_messagebus *p = messagebus;
    enum sys_message msg = 0;

    // drivers/timer0a
    if (timer_a0_last_event) {
        msg |= timer_a0_last_event;
        timer_a0_last_event = 0;
    }
    // drivers/uart0
    if (uart0_last_event & UART0_EV_RX) {
        msg |= BITA;
        uart0_last_event = 0;
    }
    // drivers/uart1
    if (uart1_last_event & UART1_EV_RX) {
        msg |= BITB;
        uart1_last_event = 0;
    }
    // drivers/rtca
    if (rtca_last_event & RTCA_EV_SECOND) {
        msg |= BITF;
        rtca_last_event = 0;
    }
    while (p) {
        // notify listener if he registered for any of these messages
        if (msg & p->listens) {
            p->fn(msg);
        }
        p = p->next;
    }
}

void settings_init(uint8_t * addr, const uint8_t location)
{
    uint8_t *src_p, *dst_p;
    uint8_t i;

    src_p = addr;
    dst_p = (uint8_t *) & s;
    if (((*src_p) != FLASH_VER) || (location)) {
        src_p = (uint8_t *) & defaults;
    }
    for (i = 0; i < sizeof(s); i++) {
        *dst_p++ = *src_p++;
    }
}

void settings_apply()
{
}

void adc_read()
{
    uint16_t q_bat = 0, q_raw = 0;
    uint32_t v_bat, v_raw;

    adc10_read(3, &q_bat, REFVSEL_1);
    adc10_read(2, &q_raw, REFVSEL_1);
    v_bat = (uint32_t) q_bat *s.vref * DIV_BAT / 10000;
    v_raw = (uint32_t) q_raw *s.vref * DIV_RAW / 10000;
    stat.v_bat = v_bat;
    stat.v_raw = v_raw;
    adc10_halt();
}

void store_pkt()
{
    uint32_t i;
    uint32_t me_temp;
    uint8_t suffix = 0xff;
    uint8_t payload_content_desc = 0;
    uint16_t rv = 0;

    me_temp = m.e;

    adc_read();

    if (!(s.settings & CONF_IGNORE_CELL_LOC)) {
        for (i = 0; i < 4; i++) {
            if ((sim900.cell[i].cellid != 65535) && (sim900.cell[i].cellid != 0)) {
                payload_content_desc = i + 1;
            }
        }
    }

    if (mc_f.fix) {
        payload_content_desc |= GPS_FIX_PRESENT;
#ifdef CONFIG_GEOFENCE
        payload_content_desc |= GEOFENCE_PRESENT;
        geofence_calc();
#endif
    }

#ifndef DEBUG_GPRS
    if (payload_content_desc == 0) {
        return;
    }
#endif

    rv += fm24_write((uint8_t *) & stat.http_post_version, m.e, 2);
    rv += fm24_write((uint8_t *) sim900.imei, m.e, 15);
    rv += fm24_write((uint8_t *) & s.settings, m.e, 2);
    rv += fm24_write((uint8_t *) & stat.v_bat, m.e, 2);
    rv += fm24_write((uint8_t *) & stat.v_raw, m.e, 2);
    rv += fm24_write((uint8_t *) & sim900.err, m.e, 2);
    rv += fm24_write((uint8_t *) & stat.fix_id, m.e, 2);
    rv += fm24_write((uint8_t *) & payload_content_desc, m.e, 1);

    if (mc_f.fix) {
        //fm24_write((uint8_t *) &mc_f, 25); // epic fail, struct not continguous
        rv += fm24_write((uint8_t *) & mc_f.year, m.e, 2);
        rv += fm24_write((uint8_t *) & mc_f.month, m.e, 1);
        rv += fm24_write((uint8_t *) & mc_f.day, m.e, 1);
        rv += fm24_write((uint8_t *) & mc_f.hour, m.e, 1);
        rv += fm24_write((uint8_t *) & mc_f.minute, m.e, 1);
        rv += fm24_write((uint8_t *) & mc_f.second, m.e, 1);

        rv += fm24_write((uint8_t *) & mc_f.lat, m.e, 4);
        rv += fm24_write((uint8_t *) & mc_f.lon, m.e, 4);
        rv += fm24_write((uint8_t *) & mc_f.pdop, m.e, 2);
        rv += fm24_write((uint8_t *) & mc_f.speed, m.e, 2);
        rv += fm24_write((uint8_t *) & mc_f.heading, m.e, 2);
        rv += fm24_write((uint8_t *) & mc_f.fixtime, m.e, 4);
#ifdef CONFIG_GEOFENCE
        rv += fm24_write((uint8_t *) & geo.distance, m.e, 4);
        rv += fm24_write((uint8_t *) & geo.bearing, m.e, 2);
#endif
    } else {
        // since gps is not available RTC time will be used
        rv += fm24_write((uint8_t *) & rtca_time.year, m.e, 2);
        rv += fm24_write((uint8_t *) & rtca_time.mon, m.e, 1);
        rv += fm24_write((uint8_t *) & rtca_time.day, m.e, 1);
        rv += fm24_write((uint8_t *) & rtca_time.hour, m.e, 1);
        rv += fm24_write((uint8_t *) & rtca_time.min, m.e, 1);
        rv += fm24_write((uint8_t *) & rtca_time.sec, m.e, 1);
    }

    if (payload_content_desc & 0x7) {
        // tower cell data
        rv += fm24_write((uint8_t *) & sim900.cell[0], m.e,
               (payload_content_desc & 0x7) * sizeof(sim900_cell_t));
        memset(&sim900.cell, 0, sizeof(sim900_cell_t));
    }

    // suffix
    rv += fm24_write((uint8_t *) & suffix, m.e, 1);

    if (rv < 31) {
        sim900.err |= ERR_RAM_WRITE;
    }

    stat.fix_id++;

    // reset values
    for (i = 0; i < 4; i++) {
        sim900.cell[i].cellid = 0;
    }
    mc_f.fix = 0;

    // organize data into < MAX_SEG_SIZE byte segments
    if (fm24_data_len(m.seg[m.seg_num - 1], m.e) > MAX_SEG_SIZE) {
        if (m.seg_num == MAX_SEG) {
            // drop oldest segment
            for (i = 0; i < MAX_SEG; i++) {
                m.seg[i] = m.seg[i+1];
            }
            m.seg_num--;
        }

        // create new segment
        m.seg[m.seg_num] = me_temp;
        m.seg[m.seg_num+1] = m.e;
        m.seg_num++;

    } else {
        // just concatenate to the current segment
        // and mark the end of the segment
        m.seg[m.seg_num] = m.e;
    }

    // see if a data upload is needed
#ifdef CONFIG_GEOFENCE
    if (geo.distance > s.geofence_trigger) {
        geo.distance = 0;
        movement_next = rtca_time.sys + 600;
        if (!(gprs_tx_trig & TG_NOW_MOVING)) {
            gprs_tx_trig |= TG_NOW_MOVING;
            sim900.flags |= TX_FIX_RDY;
            gprs_tx_next = rtca_time.sys + s.gprs_moving_tx_interval;
        }
    } else {
        if (rtca_time.sys > movement_next) {
            gprs_tx_trig &= ~TG_NOW_MOVING;
        }
    }
#endif

    // if only 2 more segments can be created
    if (m.seg_num > MAX_SEG - 3) {
        sim900.flags |= TX_FIX_RDY;
    }

#ifdef DEBUG_GPRS
    snprintf(str_temp, STR_LEN, "e: %lu\tseg_num: %d\twb: %u\r\n", m.e, m.seg_num, rv);
    uart0_tx_str(str_temp, strlen(str_temp));

    for (i=0;i < m.seg_num+1;i++) {
        snprintf(str_temp, STR_LEN, "seg[%lu]: %lu\r\n", i, m.seg[i]);
        uart0_tx_str(str_temp, strlen(str_temp));
    }
    uart0_tx_str("\r\n", 2);

    if (sim900.flags & TX_FIX_RDY) {
        uart0_tx_str("rdy\r\n", 5);
    }
#endif

}

void gps_enable(void)
{
    P6OUT |= BIT0;
    P4SEL |= 0xc;
}

void gps_disable(void)
{
    P6OUT &= ~BIT0;
    P4SEL &= ~0xc;
}

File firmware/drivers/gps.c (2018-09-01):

// minimal NMEA parser library. decodes GPRMC and GPGSA sentences
// checksum is ignored
//
//   author:          Petre Rodan <2b4eda@subdimension.ro>
//   available from:  https://github.com/rodan/
//   license:         GNU GPLv3

#include <string.h>
#include <stdio.h>
#include <math.h>

#include "drivers/rtc.h"
#include "drivers/gps.h"
#include "drivers/helper.h"
#include "proj.h"

#ifdef DEBUG_GPS
#include "drivers/uart1.h"
#endif

/// function that parses one full nmea sentence
/// input
///   s   - pointer to the beginning of the nmea string
///   len - size of the string
/// returns
///   EXIT_FAILURE - if string is malformed or too short to contain valid fix
///   EXIT_SUCCESS - if all went well
uint8_t nmea_parse(char *s, const uint8_t len)
{
    char *p = s;
    char *np, *nd;
    uint32_t tmp32 = 0;
    uint16_t tmp16 = 0;
    uint8_t i;
    uint16_t dlen, rlen;
    uint8_t *dst_p, *src_p;

    if (strstr(s, "RMC")) {
        if (len < 65) {
            return EXIT_FAILURE;
        }
        // time
        p = strchr(p, ',') + 1;
        np = strchr(p, ',');
        if ((np - p) > 5) {
            // only parse 6 digits thus ignore milliseconds
            if ( str_to_uint32(p, &tmp32, 0, 6, 0, 235959) == EXIT_FAILURE ) {
                return EXIT_FAILURE;
            }
            mc_t.hour = tmp32 / 10000;
            mc_t.minute = (tmp32 % 10000) / 100;
            mc_t.second = (tmp32 % 100);
        }

        // fix
        p = strchr(p, ',') + 1;
        if (p[0] == 'A') {
            mc_t.fix = true;
        } else if (p[0] == 'V') {
            mc_t.fix = false;
            return EXIT_FAILURE;
        } else {
            return EXIT_FAILURE;
        }

        // latitude
        p = strchr(p, ',') + 1;
        np = strchr(p, ',');
        nd = strchr(p, '.');
        dlen = nd - p;
        rlen = np - nd - 1;
        if ((dlen == 4) && (rlen == 4)) {
            if ( str_to_uint16(p, &tmp16, 0, dlen, 0, 9000) == EXIT_FAILURE ) {
                return EXIT_FAILURE;
            }
            mc_t.lat_deg = tmp16 / 100;
            mc_t.lat_min = tmp16 % 100;
            if ( str_to_uint16(p + dlen + 1, &mc_t.lat_fr, 0, rlen, 0, 9999) == EXIT_FAILURE ) {
                return EXIT_FAILURE;
            }
        }

        // lat_suffix
        p = strchr(p, ',') + 1;
        if (p[0] == 'N') {
            mc_t.lat_suffix = 'N';
        } else if (p[0] == 'S') {
            mc_t.lat_suffix = 'S';
        } else if (p[0] == ',') {
            mc_t.lat_suffix = 0x20;
        } else {
            return EXIT_FAILURE;
        }

        // longitude
        p = strchr(p, ',') + 1;
        np = strchr(p, ',');
        nd = strchr(p, '.');
        dlen = nd - p;
        rlen = np - nd - 1;
        if ((dlen == 5) && (rlen == 4)) {
            if ( str_to_uint16(p, &tmp16, 0, dlen, 0, 18000) == EXIT_FAILURE ) {
                return EXIT_FAILURE;
            }
            mc_t.lon_deg = tmp16 / 100;
            mc_t.lon_min = tmp16 % 100;
            if ( str_to_uint16(p + dlen + 1, &mc_t.lon_fr, 0, rlen, 0, 9999) == EXIT_FAILURE ) {
                return EXIT_FAILURE;
            }
        }

        // lon_suffix
        p = strchr(p, ',') + 1;
        if (p[0] == 'W') {
            mc_t.lon_suffix = 'W';
        } else if (p[0] == 'E') {
            mc_t.lon_suffix = 'E';
        } else if (p[0] == ',') {
            mc_t.lon_suffix = 0x20;
        } else {
            return EXIT_FAILURE;
        }

        // speed
        p = strchr(p, ',') + 1;
        np = strchr(p, ',');
        nd = strchr(p, '.');
        dlen = nd - p;
        if ((dlen > 0) && (dlen < (np - p))) {
            str_to_uint16(p, &mc_t.speed, 0, dlen, 0, 300);
        }

        // heading
        p = strchr(p, ',') + 1;
        np = strchr(p, ',');
        nd = strchr(p, '.');
        dlen = nd - p;
        if ((dlen > 0) && (dlen < (np - p))) {
            str_to_uint16(p, &mc_t.heading, 0, dlen, 0, 359);
        }

        // date
        p = strchr(p, ',') + 1;
        np = strchr(p, ',');
        if ((np - p) > 5) {
            if ( str_to_uint32(p, &tmp32, 0, 6, 10000, 311299) == EXIT_FAILURE ) {
                return EXIT_FAILURE;
            }
            mc_t.day = tmp32 / 10000;
            mc_t.month = (tmp32 % 10000) / 100;
            mc_t.year = (tmp32 % 100) + 2000;
        }

        mc_t.fixtime = rtca_time.sys;

#ifdef CONFIG_POSITION_AVERAGING
        float tmp_f;

        mean_pos.speed_samples++;
        mean_pos.speed_sum += mc_t.speed;
        mean_pos.speed = mean_pos.speed_sum / mean_pos.speed_samples;

        if ((mc_t.speed < 1) && (mc_t.pdop < 400)) {
            mean_pos.lat += nmea_to_float(mc_t.lat_deg, mc_t.lat_min, mc_t.lat_fr, mc_t.lat_suffix);
            mean_pos.lon += nmea_to_float(mc_t.lon_deg, mc_t.lon_min, mc_t.lon_fr, mc_t.lon_suffix);
            mean_pos.pdop += mc_t.pdop;
            mean_pos.samples++;
            tmp_f = 1000000.0 * mean_pos.lat / mean_pos.samples;
            mc_t.lat_mean = (int32_t) tmp_f;
            tmp_f = 1000000.0 * mean_pos.lon / mean_pos.samples;
            mc_t.lon_mean = (int32_t) tmp_f;
            tmp_f = mean_pos.pdop / mean_pos.samples;
            mc_t.pdop_mean = (uint16_t) tmp_f; 
        }

        snprintf(str_temp, STR_LEN, "%u\t%u\tpos %ld %ld\r\n",
                 mean_pos.samples, mean_pos.speed_sum,
                 mc_t.lat_mean, mc_t.lon_mean);
        uart1_tx_str(str_temp, strlen(str_temp));
#endif

#ifdef DEBUG_GPS
        snprintf(str_temp, STR_LEN, "t %d %d.%04d%c %d %d.%04d%c  %lds %d %dkn\r\n",
                 mc_t.lat_deg, mc_t.lat_min, mc_t.lat_fr, mc_t.lat_suffix,
                 mc_t.lon_deg, mc_t.lon_min, mc_t.lon_fr, mc_t.lon_suffix,
                 rtca_time.sys - mc_t.fixtime, mc_t.pdop, mc_t.speed);
        uart1_tx_str(str_temp, strlen(str_temp));
#endif

        if (mc_f.pdop == 0) {
            mc_f.pdop = 9999;
        }

        if (mc_t.fix && ((mc_t.pdop < 300) || rtc_not_set) && ((rtca_time.sys > rtca_set_next) || (rtca_time.min != mc_f.minute))) {
            rtca_time.year = mc_t.year;
            rtca_time.mon = mc_t.month;
            rtca_time.day = mc_t.day;
            rtca_time.hour = mc_t.hour;
            rtca_time.min = mc_t.minute;
            rtca_time.sec = mc_t.second;

            rtca_set_time();
            rtc_not_set = 0;
            rtca_set_next += RTC_SET_INTERVAL;
        }

        if (mc_t.fix && (mc_t.pdop <= mc_f.pdop)) {

            mc_t.lat = nmea_to_float(mc_t.lat_deg, mc_t.lat_min, mc_t.lat_fr, mc_t.lat_suffix);
            mc_t.lon = nmea_to_float(mc_t.lon_deg, mc_t.lon_min, mc_t.lon_fr, mc_t.lon_suffix);

            src_p = (uint8_t *) & mc_t;
            dst_p = (uint8_t *) & mc_f;
            for (i = 0; i < sizeof(mc_t); i++) {
                *dst_p++ = *src_p++;
            }
            memset(&mc_t, 0, sizeof(mc_t));
        }
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

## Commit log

2013-11-10 add firmware
    [adc_calibration.ods]
2013-11-10 add uart RX capability
2013-11-24 fix ADC REFVSEL bug
    [adc.c]
2013-12-06 create sim card reader footprint
    [tracy.brd, tracy.sch]
2013-12-10 sch work
    [tracy.brd, tracy.sch]
2013-12-14 daily snapshot
    [tracy.brd, tracy.sch]
2014-01-04 pcb done
    [tracy.brd, tracy.sch]
2014-01-07 add silkscreen
    [tracy.brd, tracy.sch]
2014-07-06 add nmea parser driver
2014-07-17 shorten delay until uart1_rx_event is picked up
    [proj.c, sim900.c]
2014-07-19 activate flow control
2014-07-22 add bat voltage check
    [adc_calibration.ods]
2014-07-23 add /8 divider to timer_A0
2014-07-28 fix http reply detection
    [sim900.c]
2014-08-05 keepout under fuse
    [tracy.brd, tracy.sch]
2014-08-09 make sure timers are started before sim900_tx, further divide clock by 8
2014-08-23 add fram buffer
    [tracy.brd, tracy.sch]
2014-09-01 rev 2
    [tracy.brd, tracy.sch]
2014-09-02 optionally send voltages
    [adc_calibration.ods]
2014-09-04 add buck converter board
    [buck.brd, buck.sch]
2014-09-05 use memset to reset last fix
    [proj.c]
2014-09-08 vref saved to flash
    [adc_calibration.ods]
2014-09-11 hopefully proper gprs connection reset upon fail
    [proj.c, sim900.c]
2014-09-15 reset sim900.err after sending it
    [proj.c, proj.h, sim900.c]
2014-10-02 move silkscreen labels
    [buck.brd, buck.sch, tracy.brd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]
2014-10-16 fill up currents in manual
2014-10-17 fix 4 char sms commands
    [proj.h, sim900.c]
2014-10-18 fix reset to defaults sms tx
    [sim900.c]
2014-10-22 manual update
    [tracy.brd, tracy.sch]
2014-11-28 remove adc calibration
    [adc_calibration.ods]
2014-12-10 controlled charging
2014-12-18 read adc during pkt store
2015-08-27 battery charge condition changed
2018-12-07 longer failure blackout intervals
    [qa.c]

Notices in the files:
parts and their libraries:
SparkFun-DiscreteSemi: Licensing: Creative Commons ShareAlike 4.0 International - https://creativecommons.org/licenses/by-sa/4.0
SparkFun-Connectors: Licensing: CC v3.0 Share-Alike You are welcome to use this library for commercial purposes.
